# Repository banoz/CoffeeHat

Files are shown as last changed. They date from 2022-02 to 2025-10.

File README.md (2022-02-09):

# CoffeeHat

Basic espresso machine controls on Arduino Nano extension board.

Supports 3-Way valve control, PSM control for a vibe pump based on zero-crossing detector, Qwiic I2C connector for various peripherals (e.g. displays, thermal sensors), full header breakout for Nano pins.

# DISCLAIMER

This project is provided AS-IS, use at your sole discretion and your own risk. Parts of this project can work under dangerous voltages and require special care. Please don't do anything you're not sure about. The maintainer(s) can not be held liable for any suffer or loss or harm or anything else.

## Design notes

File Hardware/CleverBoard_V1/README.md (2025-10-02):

# Clever board

ESP32-C6 based controller board v1 - WIP

```
J10, J11 - AC input
J12 - pump
J13 - 3-way valve

J1 - UART0 (IO16/IO17)
J2 - I2C (IO6/IO7)
J3 - IO8, IO9
J5 - IO3
J6 - Pressure sensor (IO2, 10K/20K voltage divider)
J7 - Brew (IO22) / Steam (IO23) switch
J8 - IO19, IO20, IO21
J9 - 5V SSR control (IO10 -> SSR1, IO11 -> SSR2)

AC zero-cross sense on IO0
Pump control on IO18
3-Way valve control on IO15

I2C port on IO7(I2C1_SCL)/IO6(I2C1_SDA)
```

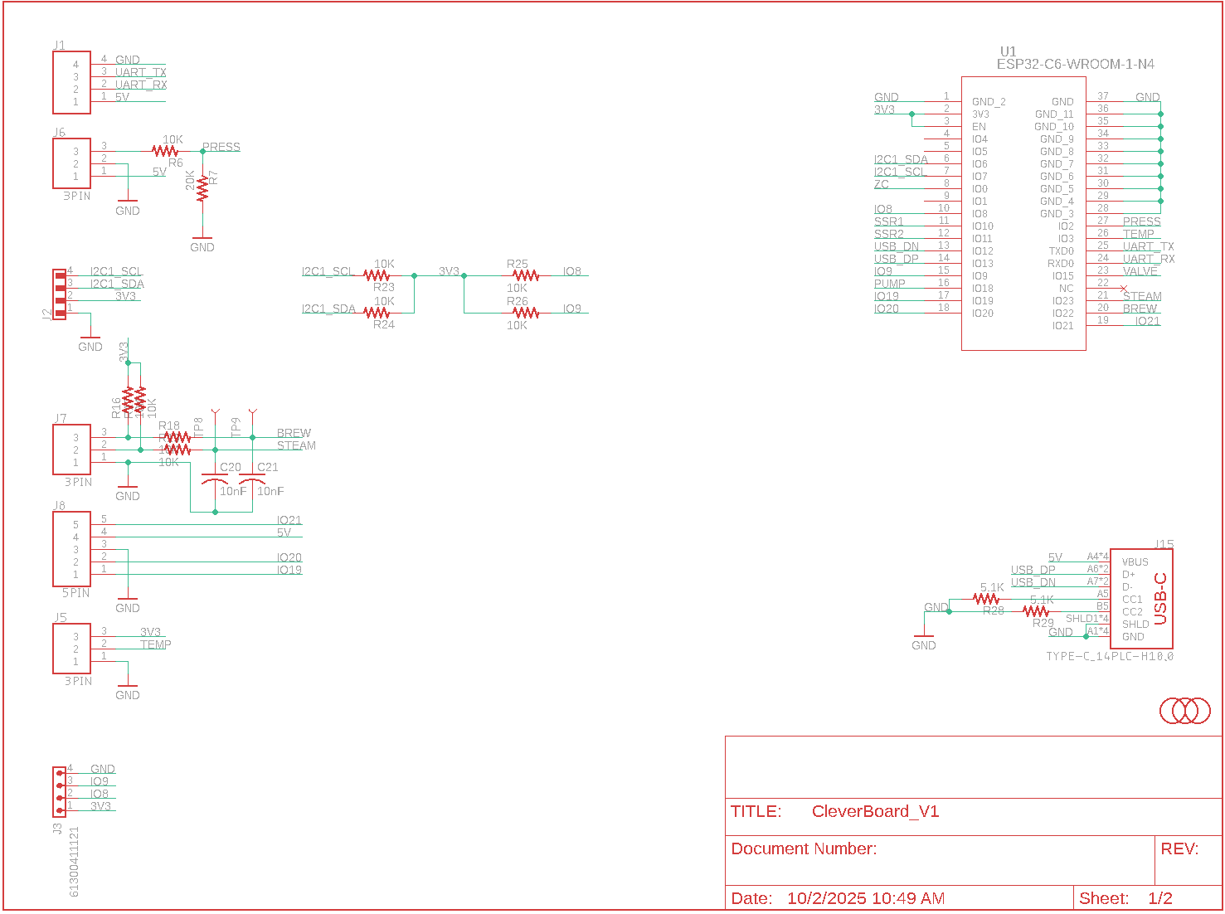
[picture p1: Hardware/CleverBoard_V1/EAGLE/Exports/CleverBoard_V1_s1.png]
CleverBoard_V1_s1

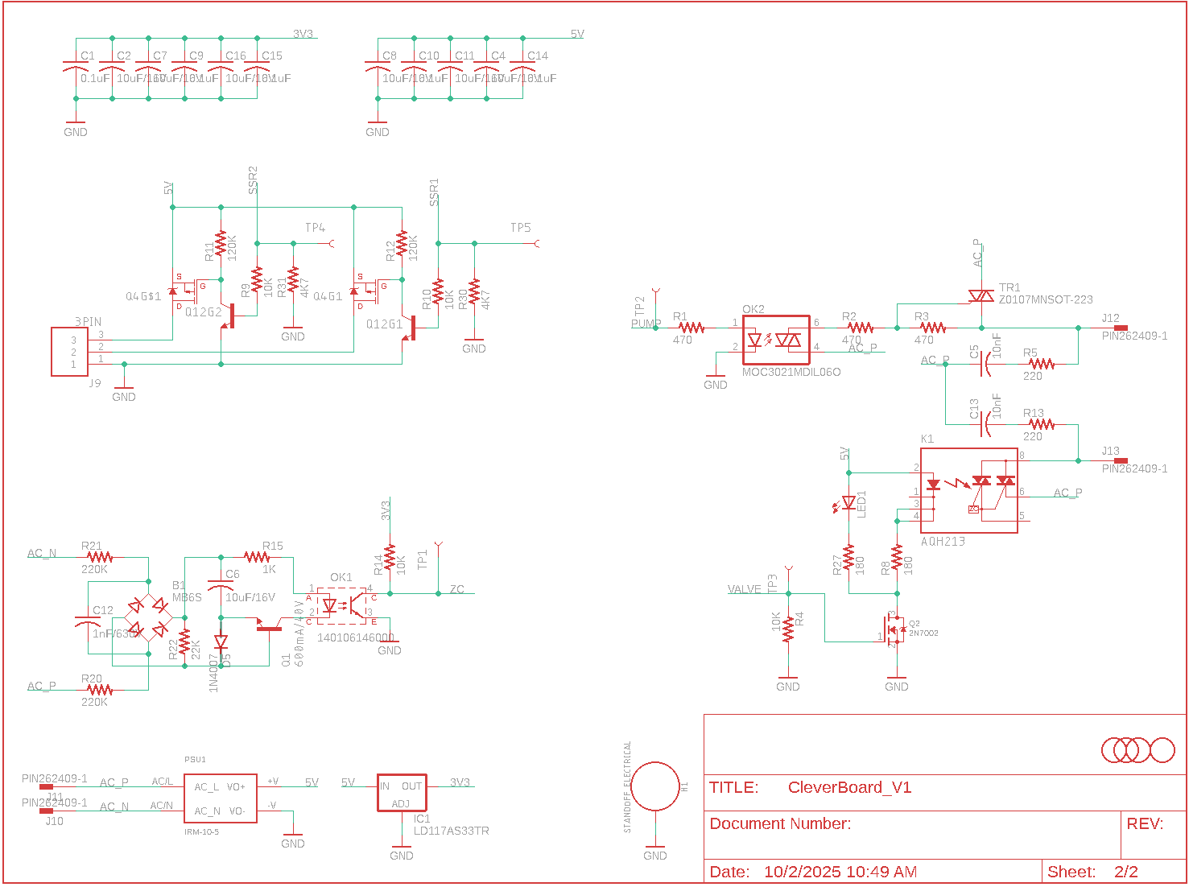
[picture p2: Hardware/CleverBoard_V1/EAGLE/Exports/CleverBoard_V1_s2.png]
CleverBoard_V1_s2


Top|Bottom
---|---
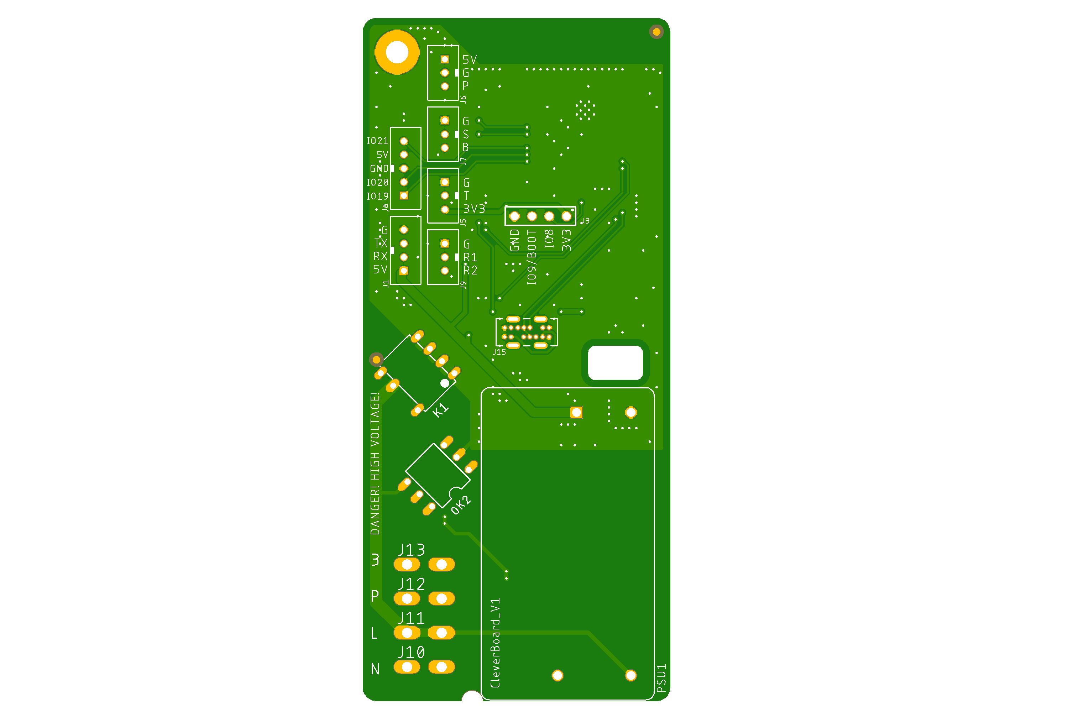
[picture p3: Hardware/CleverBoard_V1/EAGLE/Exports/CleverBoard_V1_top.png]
CleverBoard_V1_top
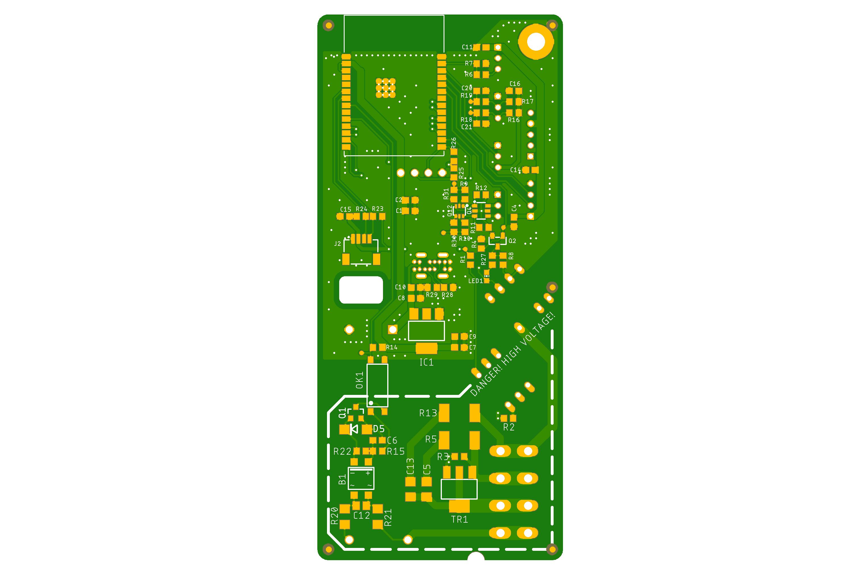
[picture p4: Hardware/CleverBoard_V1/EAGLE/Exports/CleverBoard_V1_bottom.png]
CleverBoard_V1_top
|

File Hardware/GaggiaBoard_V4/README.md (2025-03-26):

# Gaggiuino board

Gaggiuino hardware controller board v4 - WIP

```
J10, J11 - AC input
J12 - pump
J13 - 3-way valve

J1 - UART2 (PA2/PA3)
J2 - I2C
J4 - thermocouple
J5 - PA12, PB15, GND
J6 - Pressure sensor (ADS101X/ADS111X on I2C1)
J7 - Brew (PC14) / Steam (PC15) switch
J8 - Scales (PB0 -> CLK, PB8 -> D1, PB9 -> D2)
J9 - 5V SSR control (PA15 -> SSR1, PA8 -> SSR2)

AC zero-cross sense on PA0
Pump control on PA1
3-Way valve control on PC13

SPI1 is used by thermocouple amplifier on PA5(SPI1_SCK)/PB4(SPI1_MISO), and CS on PA6

I2C port on PB6(I2C1_SCL)/PB7(I2C1_SDA)

J15 - USB-C

J27 - SWD, USART1 (PA9/10), NRST and BOOT1
```

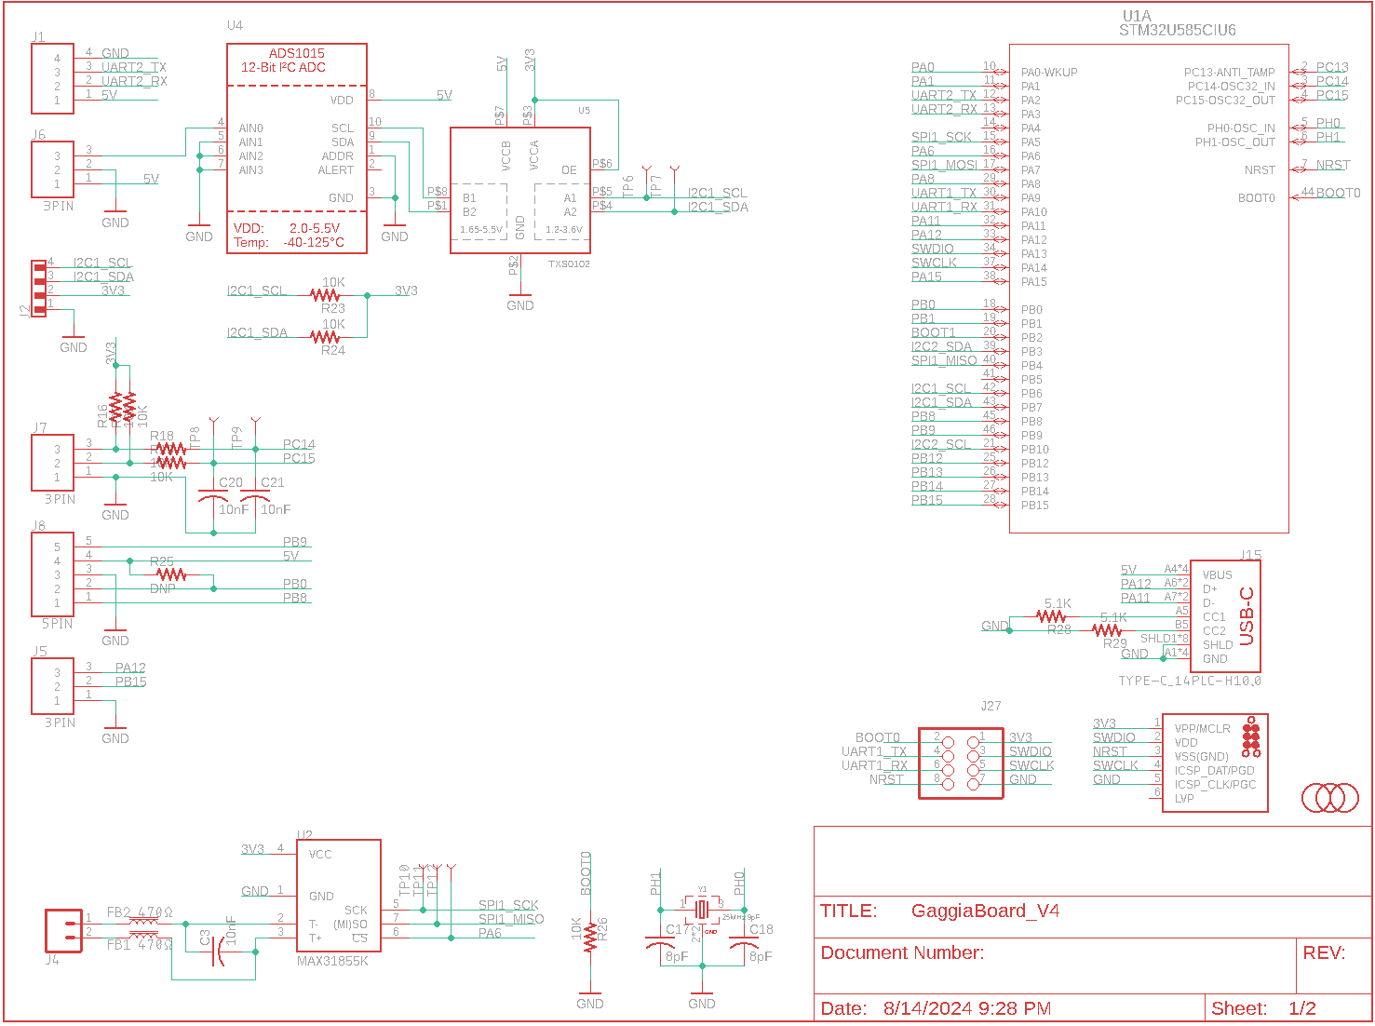
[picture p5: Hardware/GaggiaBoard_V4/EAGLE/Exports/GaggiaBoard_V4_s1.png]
GaggiaBoard_V4_s1

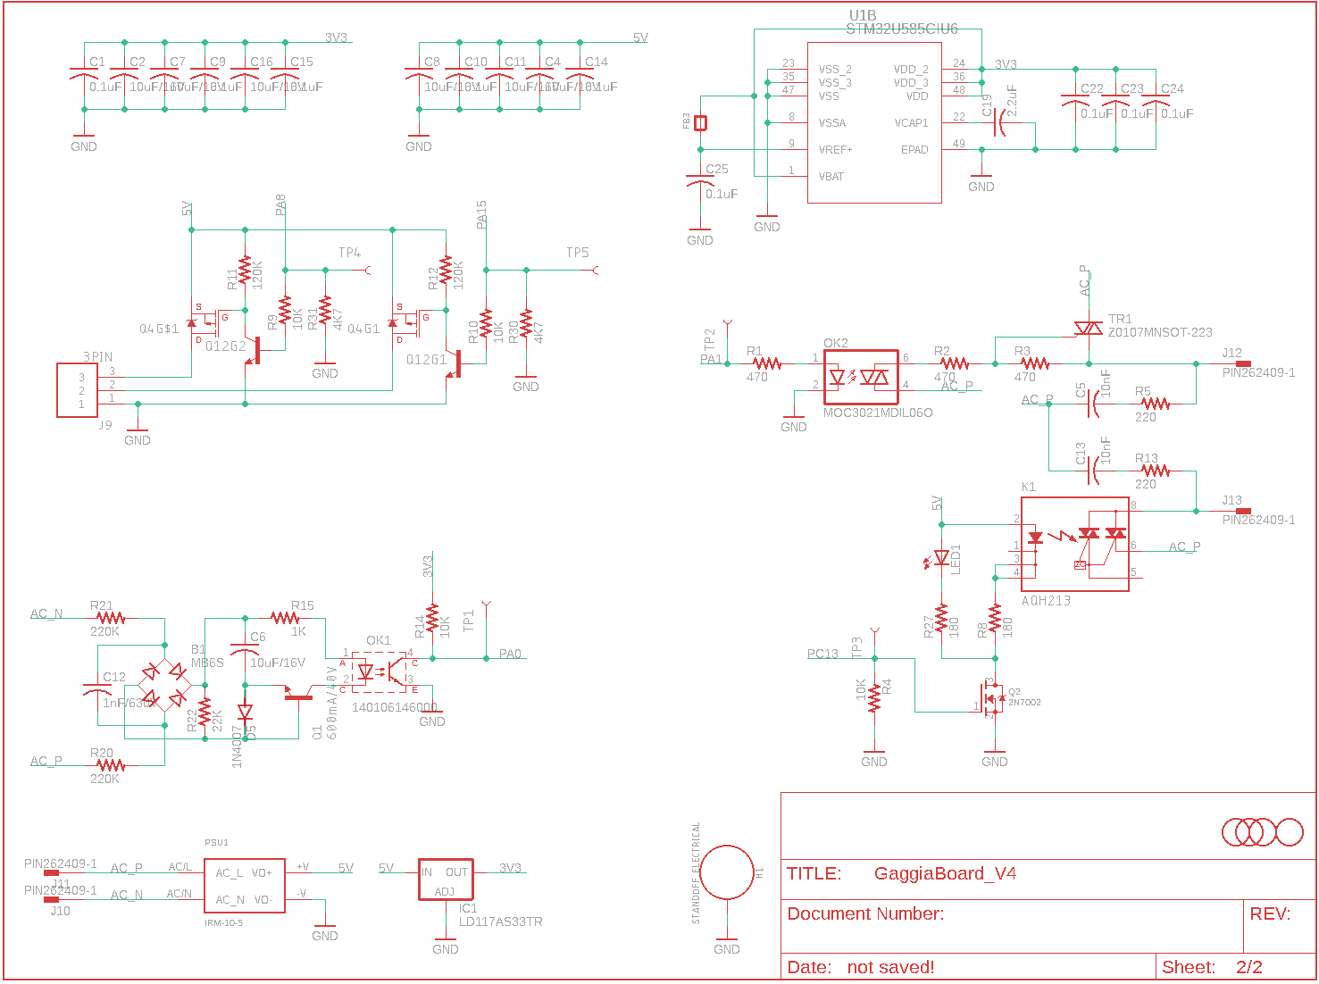
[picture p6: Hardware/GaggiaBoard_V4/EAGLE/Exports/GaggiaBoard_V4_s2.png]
GaggiaBoard_V4_s2


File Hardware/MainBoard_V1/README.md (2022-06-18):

# Generic espresso machine control board

Arduino Nano-based control board for an espresso maker.

**WIP**

SubBoard_V1 is an extension board to use on top of MainBoard_V1 for Gaggiuino.

Pin mapping:  

```
A0 - Pressure transducer

A1 - CLK  \
A2 - D1    -- dual HX711 scales
A3 - D2   /

A4 - I2C SDA
A5 - I2C SCL

D8 - Brew switch
D7 - Steam switch

D0 - NEXTION TX
D1 - NEXTION RX

D3 - AC zero-crossing

D4 - DO   \
D5 - CS    -- MAX31855
D6 - CLK  /

D9 - 3-way valve control
D10 - Pump TRIAC control
D11 - Boiler heater SSR control
```

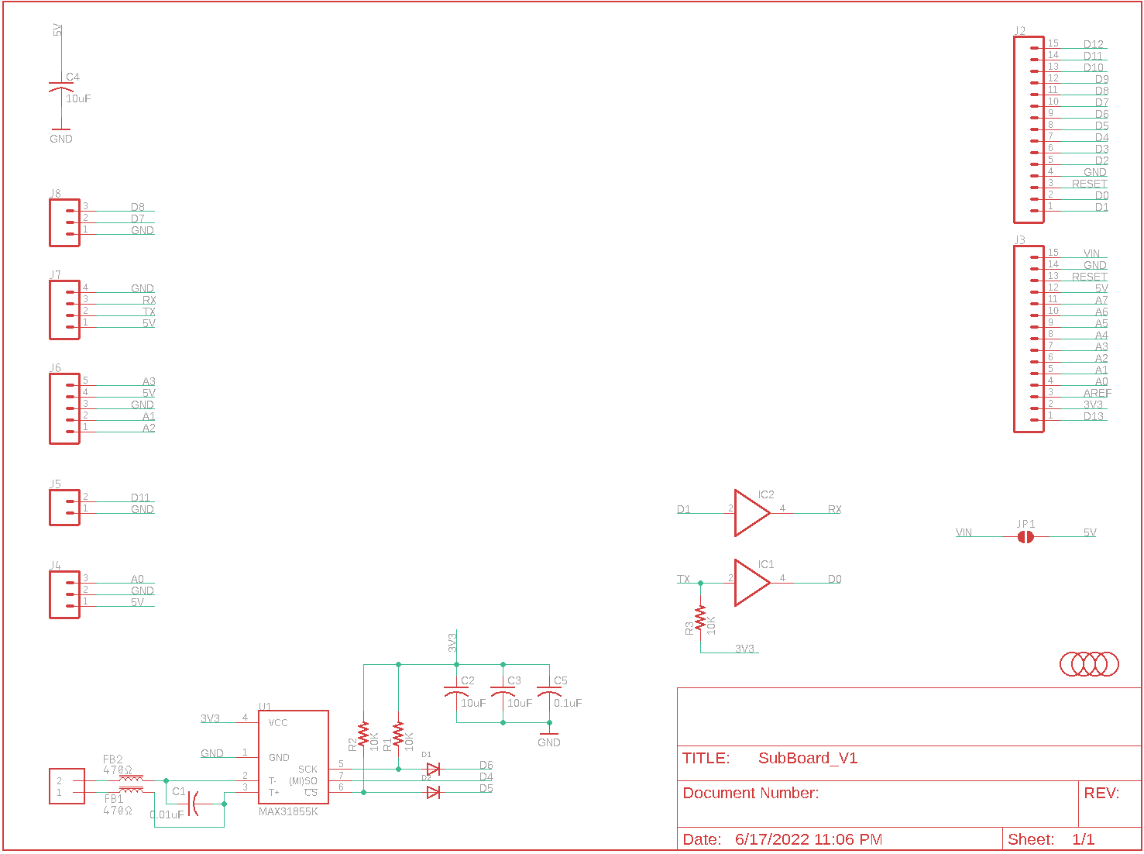
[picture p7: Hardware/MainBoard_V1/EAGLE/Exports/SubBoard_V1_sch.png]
SubBoard_V1_sch

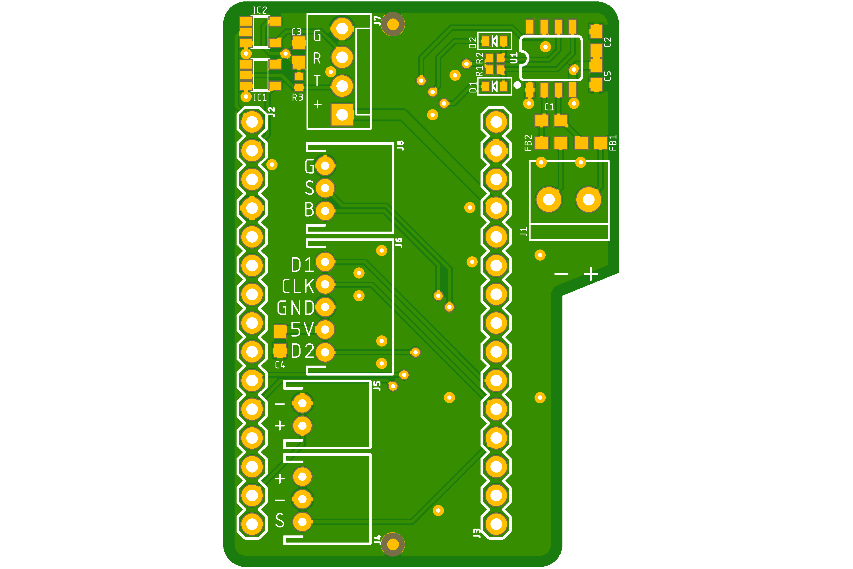
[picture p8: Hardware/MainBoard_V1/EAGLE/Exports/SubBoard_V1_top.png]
SubBoard_V1_top


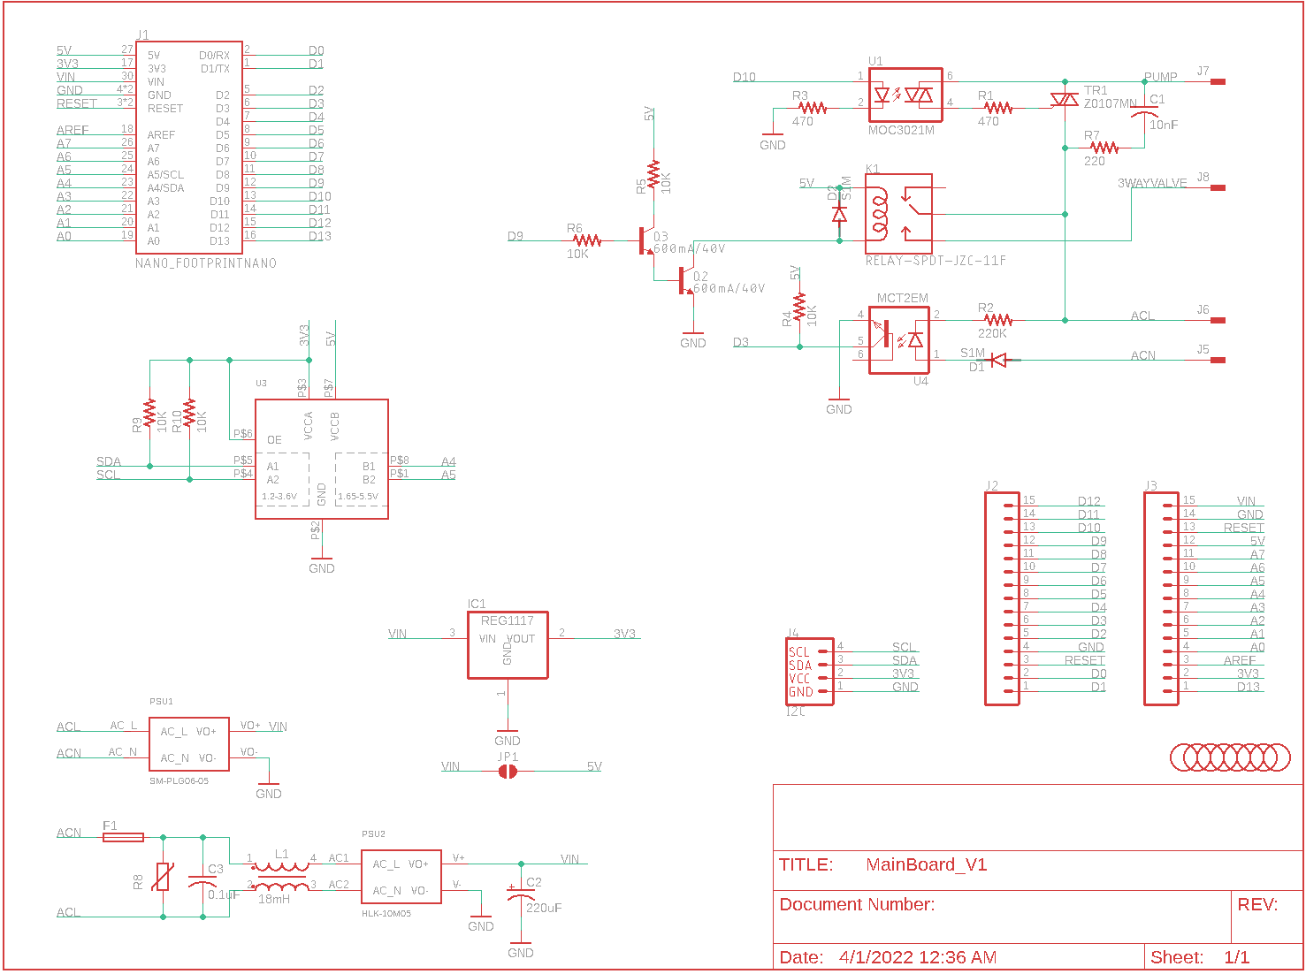
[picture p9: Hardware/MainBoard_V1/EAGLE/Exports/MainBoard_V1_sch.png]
MainBoard_V1_sch

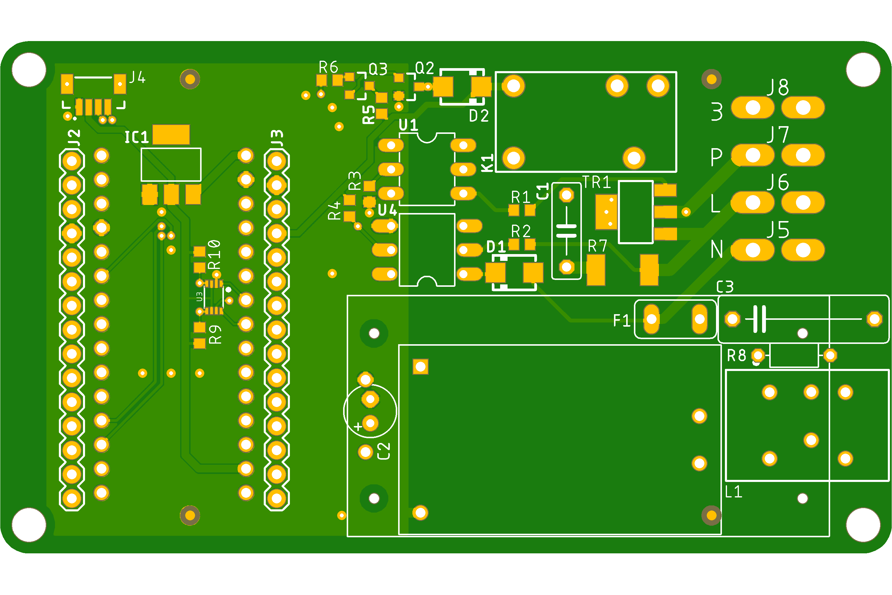
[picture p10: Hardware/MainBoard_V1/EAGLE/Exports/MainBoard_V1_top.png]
MainBoard_V1_top


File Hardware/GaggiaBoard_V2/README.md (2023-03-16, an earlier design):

# Gaggiuino board

Next-gen Gaggiuino hardware controller board - WIP

[3D model](https://github.com/banoz/banoz.github.io/blob/main/repository/stl/GaggiaBoard_V2.stl)

```
J14 - steam boiler heater element
J11 - steam boiler supply valve
J16 - 3-way valve
J17 - pump
J19, J20 - AC input

J1 - UART2 (PA2/PA3)
J2, J3 - I2Cs
J4 - thermocouple
J6 - Pressure sensor (ADS101X/ADS111X on I2C1)
J7 - Brew (PC14) / Steam (PC15) switch
J8 - Scales (PB0 -> CLK, PB8 -> D1, PB9 -> D2)
J9 - 5V SSR control (PA15 -> SSR1, PA8 -> SSR2)

AC zero-cross sense on PA0
Pump control on PA1
Buzzer on PB14
Steam boiler heater element relay on PB13
Steam boiler supply valve relay on PB12
3-Way valve control on PC13

SPI1 is used by thermocouple amplifier on PA5(SPI1_SCK)/PB4(SPI1_MISO), and CS on PA6

Two I2C ports on PB6(I2C1_SCL)/PB7(I2C1_SDA) and PB10(I2C2_SCL)/PB3(I2C2_SDA)

J27 - USART1 (PA9/10) with NRST and BOOT1
```
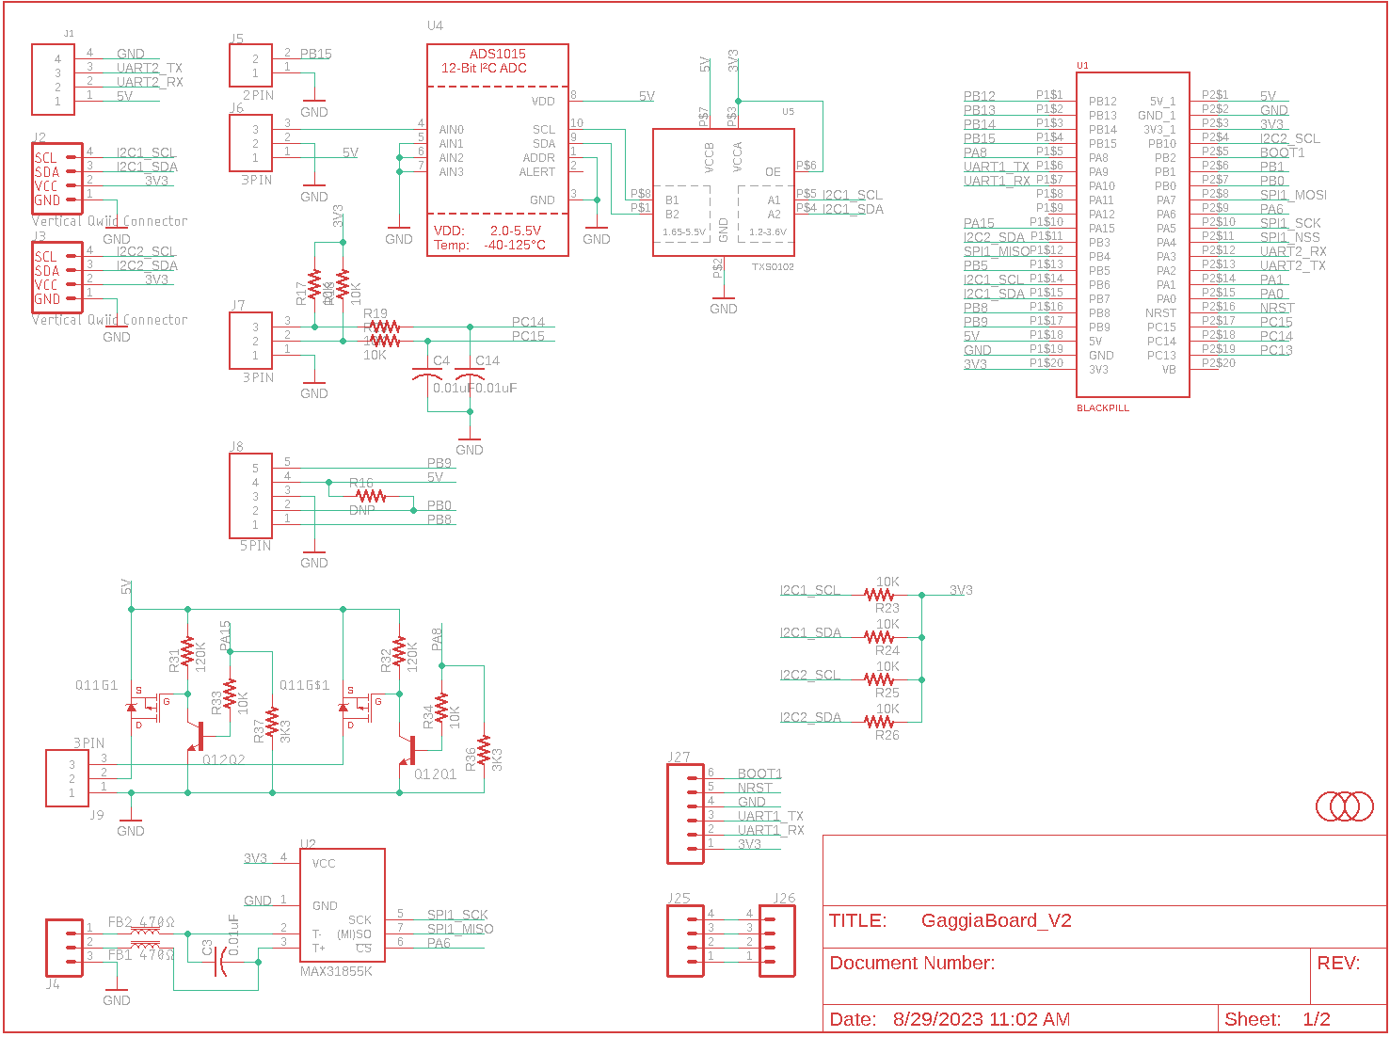
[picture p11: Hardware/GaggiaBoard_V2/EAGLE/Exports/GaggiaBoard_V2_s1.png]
GaggiaBoard_V2_s1

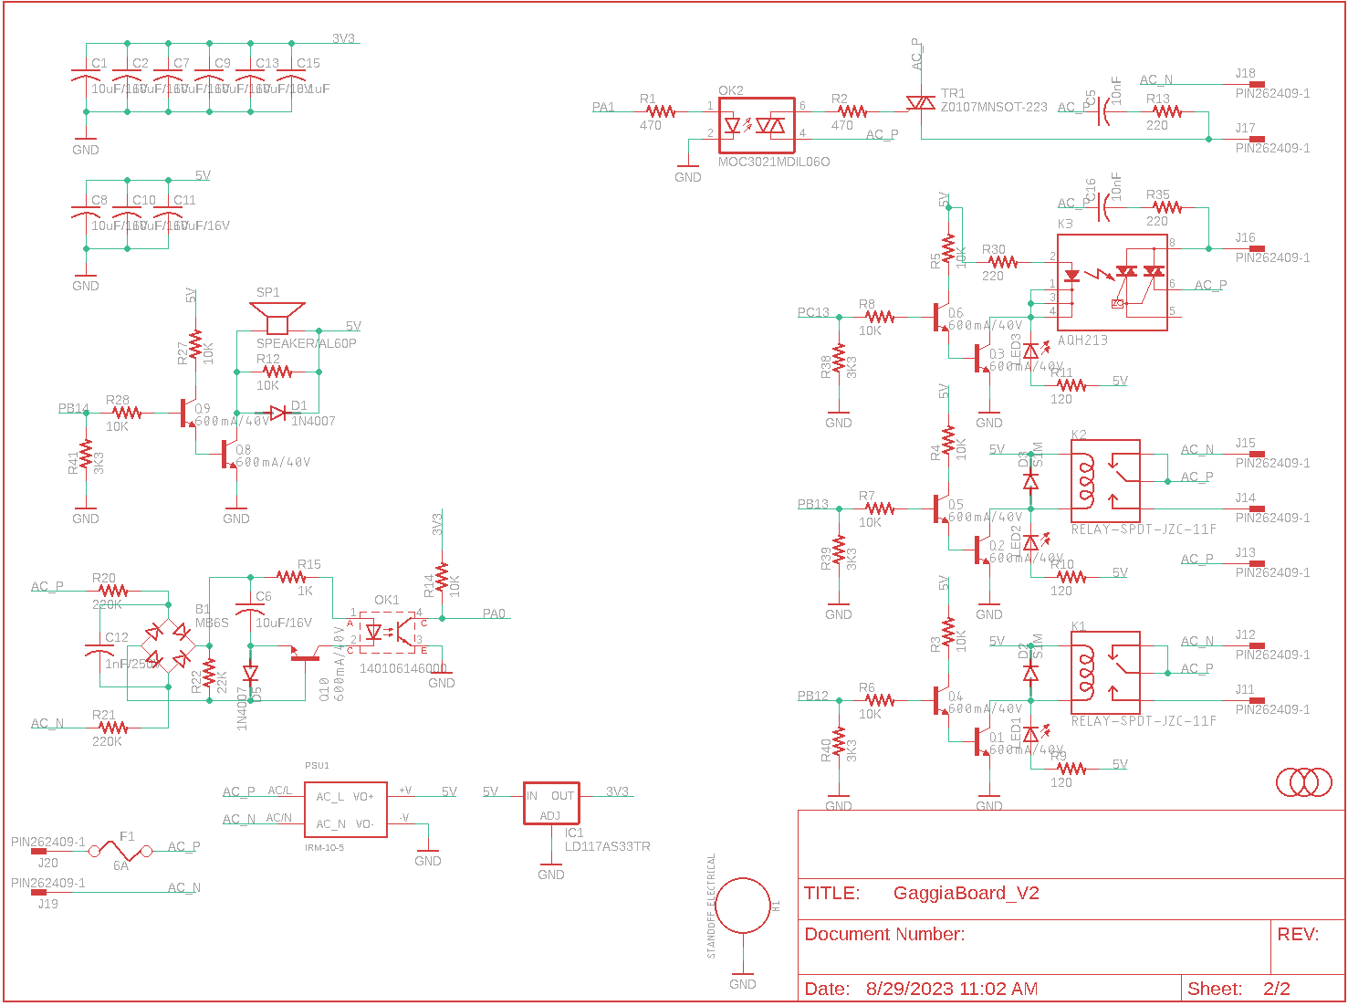
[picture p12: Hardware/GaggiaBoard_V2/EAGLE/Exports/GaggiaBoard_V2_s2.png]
GaggiaBoard_V2_s2

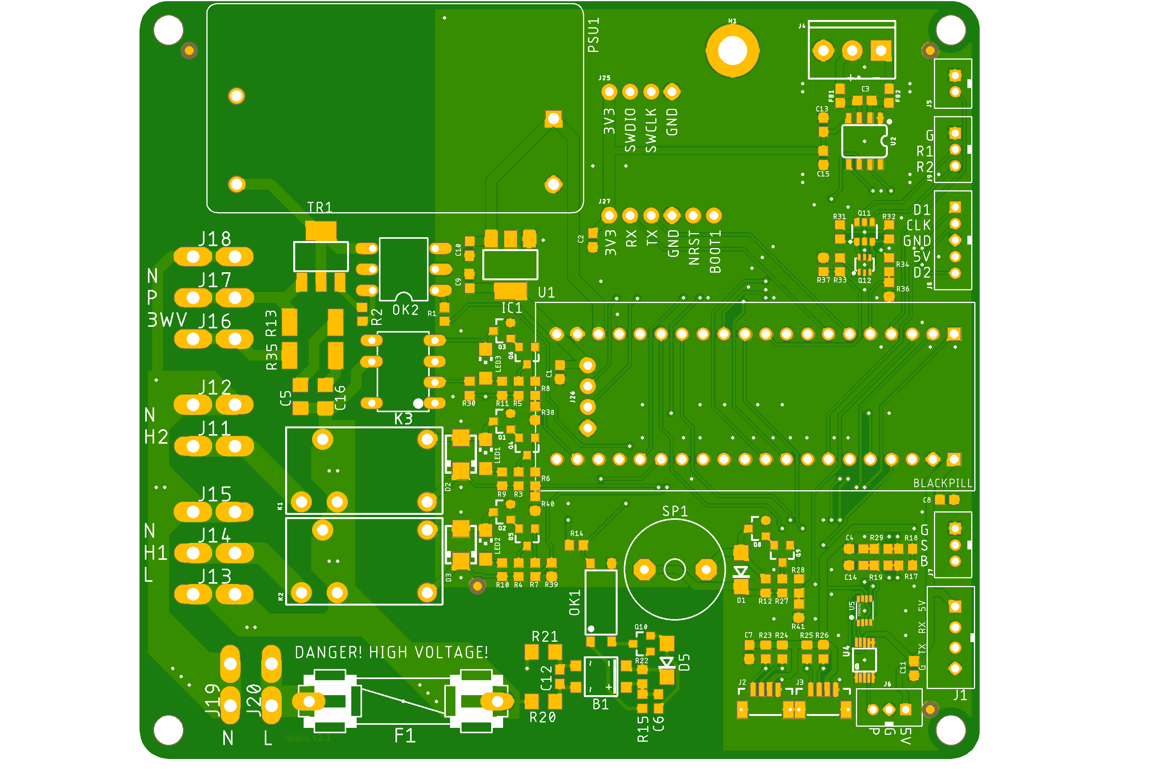
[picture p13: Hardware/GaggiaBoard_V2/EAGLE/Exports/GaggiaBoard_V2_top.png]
GaggiaBoard_V2_top


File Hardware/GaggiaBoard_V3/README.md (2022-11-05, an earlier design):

# Gaggiuino board

Gaggiuino hardware controller board v3 - WIP

[3D model](https://github.com/banoz/banoz.github.io/blob/main/repository/stl/GaggiaBoard_V3.stl)

```
J10, J11 - AC input
J12 - pump
J13 - 3-way valve

J1 - UART2 (PA2/PA3)
J2 - I2C
J4 - thermocouple
J6 - Pressure sensor (ADS101X/ADS111X on I2C1)
J7 - Brew (PC14) / Steam (PC15) switch
J8 - Scales (PB0 -> CLK, PB8 -> D1, PB9 -> D2)
J9 - 5V SSR control (PA15 -> SSR1, PA8 -> SSR2)

AC zero-cross sense on PA0
Pump control on PA1
3-Way valve control on PC13

SPI1 is used by thermocouple amplifier on PA5(SPI1_SCK)/PB4(SPI1_MISO), and CS on PA6

I2C port on PB6(I2C1_SCL)/PB7(I2C1_SDA)

J27 - USART1 (PA9/10) with NRST and BOOT1
```

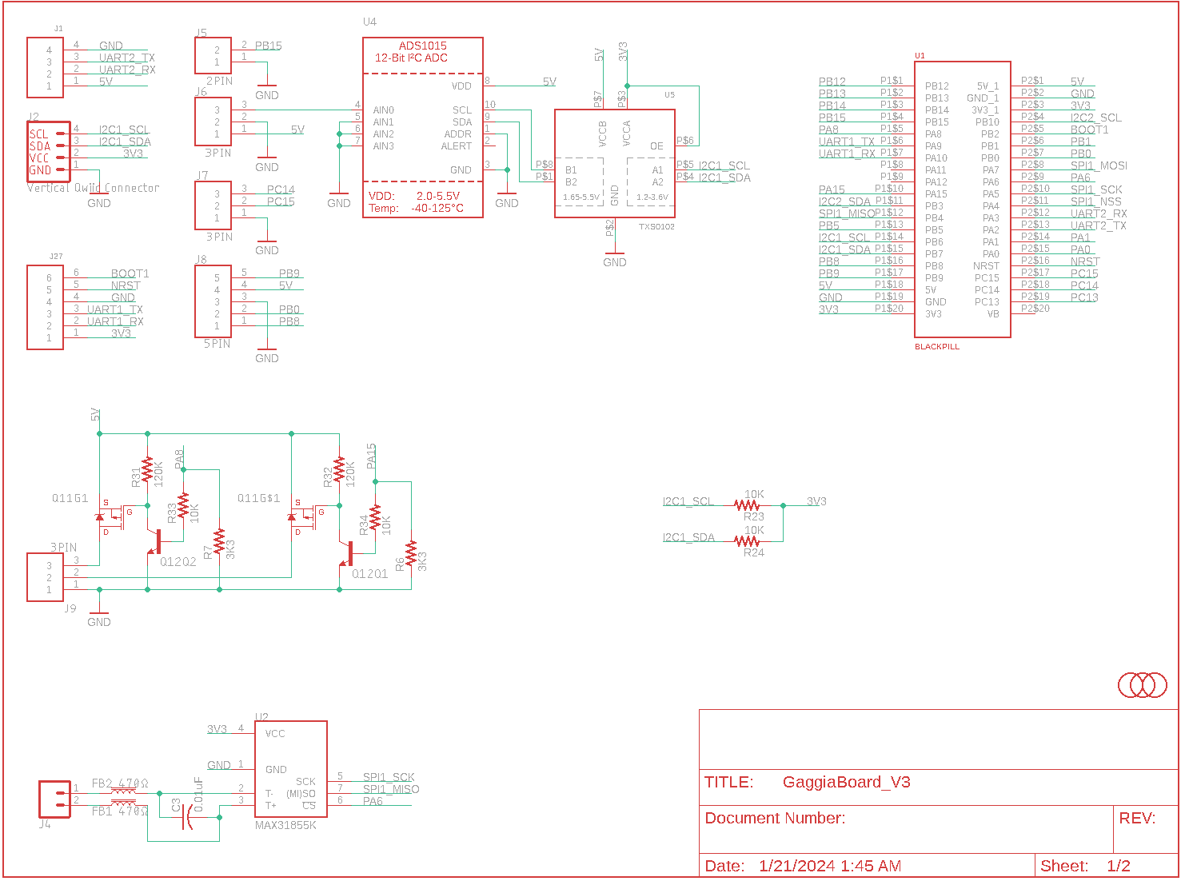
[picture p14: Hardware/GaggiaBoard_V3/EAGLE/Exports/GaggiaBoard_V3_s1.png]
GaggiaBoard_V3_s1

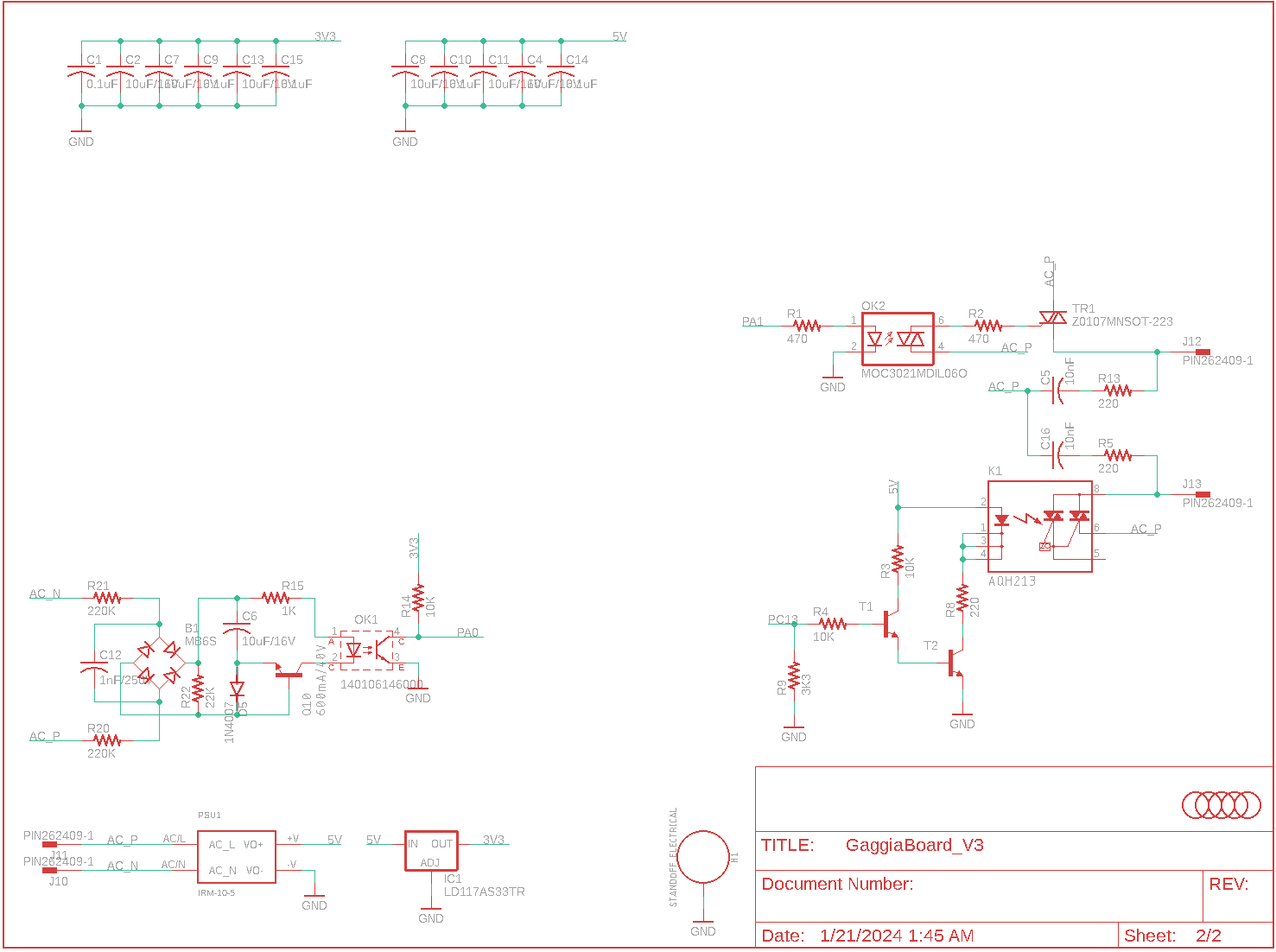
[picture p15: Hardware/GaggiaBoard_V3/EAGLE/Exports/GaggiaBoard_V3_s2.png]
GaggiaBoard_V3_s2


Top|Bottom
---|---
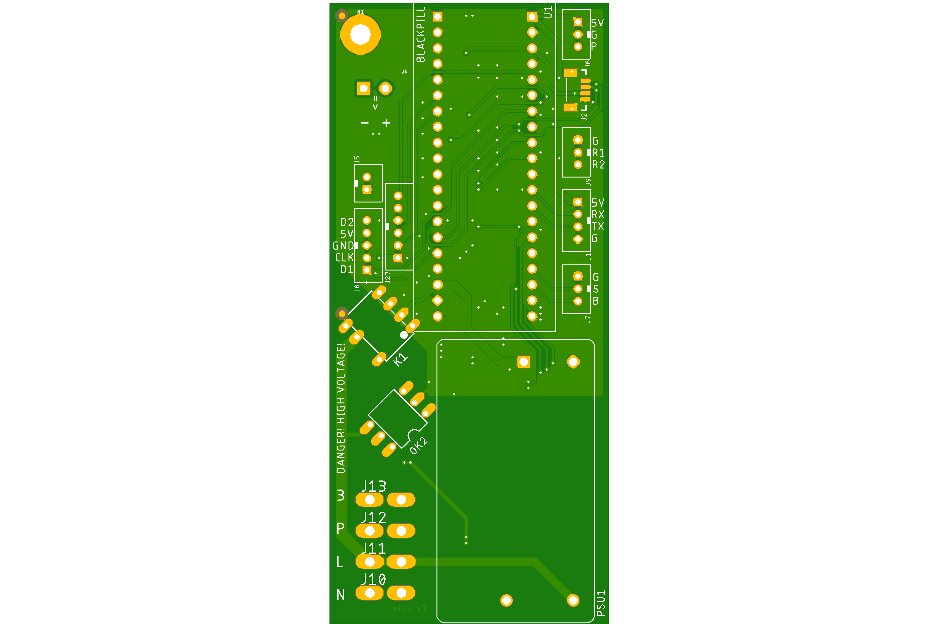
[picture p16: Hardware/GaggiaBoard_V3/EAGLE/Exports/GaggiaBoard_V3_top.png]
GaggiaBoard_V3_top
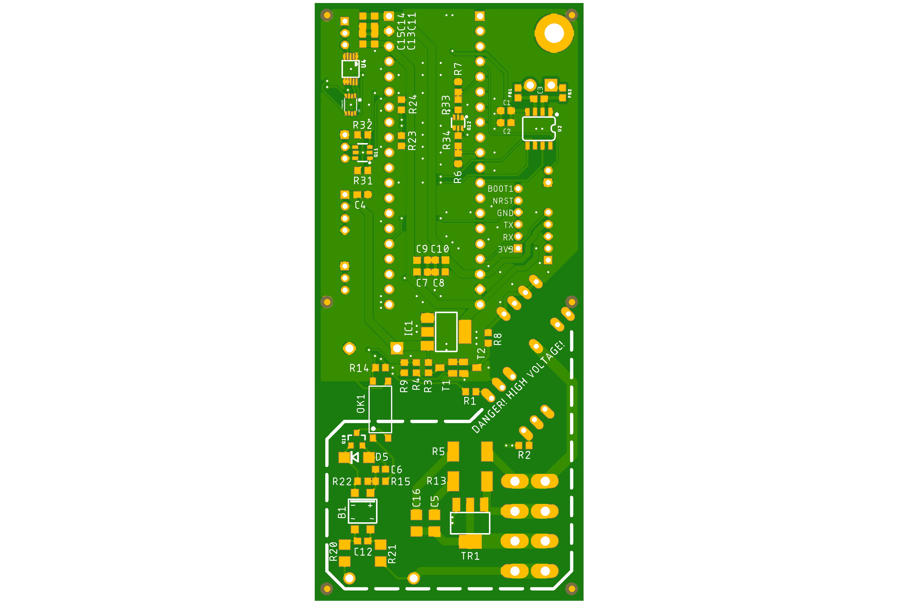
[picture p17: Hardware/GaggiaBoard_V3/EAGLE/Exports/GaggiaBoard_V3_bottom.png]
GaggiaBoard_V3_top
|

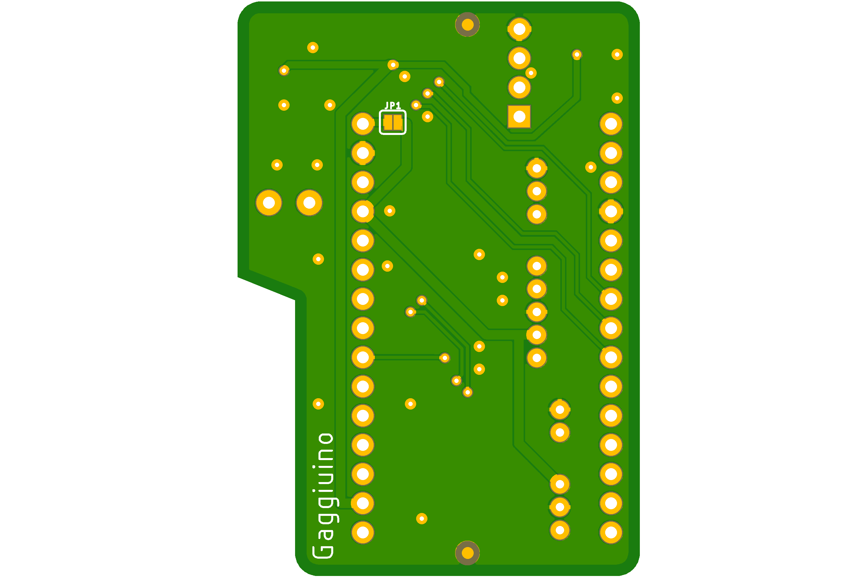
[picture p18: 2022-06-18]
Hardware/MainBoard_V1/EAGLE/Exports/SubBoard_V1_bottom.png

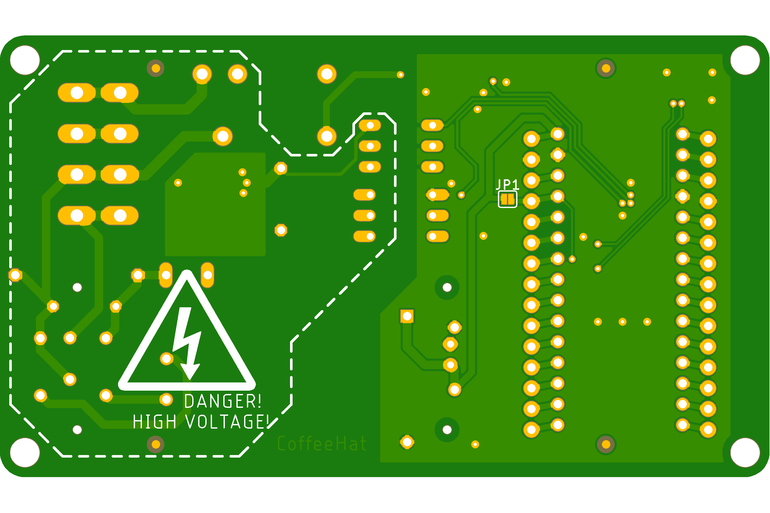
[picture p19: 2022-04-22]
Hardware/MainBoard_V1/EAGLE/Exports/MainBoard_V1_bottom.png

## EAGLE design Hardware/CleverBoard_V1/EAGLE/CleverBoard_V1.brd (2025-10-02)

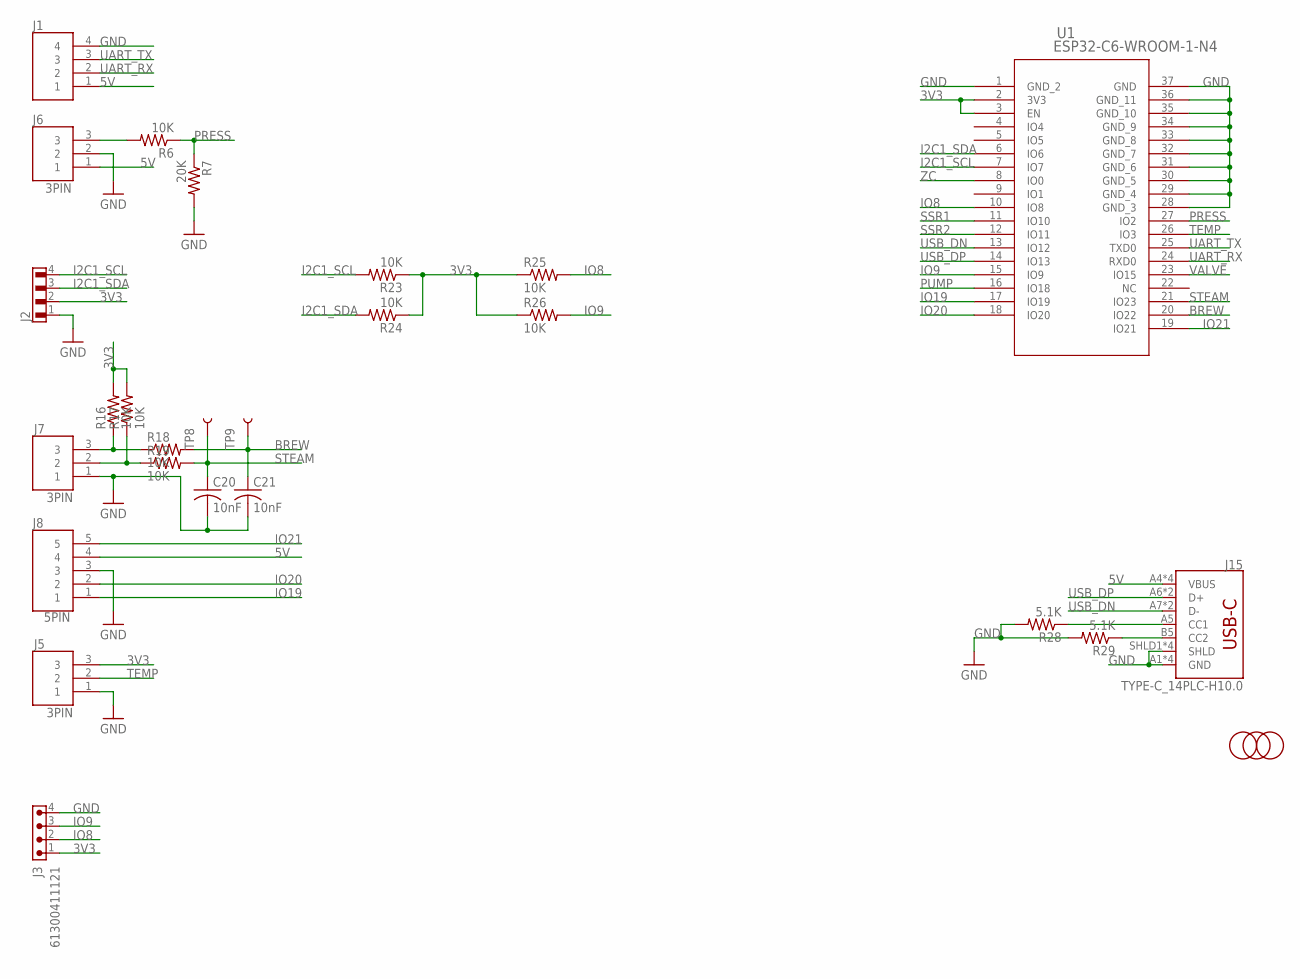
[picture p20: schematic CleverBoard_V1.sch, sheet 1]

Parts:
C20, C21: 10nF; C0603; LCSC C100042
J1: 4PIN; B4B-PH-K-S; LCSC C131334
J2: 665104131822; LCSC C160390
J3: 61300411121; LCSC C2691448
J5, J6, J7: 3PIN; B3B-PH-K-S; LCSC C131339
J8: 5PIN; B5B-PH-K-S; LCSC C157993
J15: TYPE-C_14PLC-H10.0; LCSC C3151746
MARK1, MARK2, MARK5: FIDUCIAL; FIDUCIAL_1MM
R6, R16, R17, R18, R19, R23, R24, R25, R26: 10K; R0603; LCSC C98220
R7: 20K; R0603; LCSC C105575
R28, R29: 5.1K; R0603; LCSC C105580
TP8, TP9: TEST-POINT3; PAD.03X.03
U1: ESP32-C6-WROOM-1-N4; MOD28_ESP32-C6-WROOM-1_EXP; LCSC C5366877

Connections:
3V3: J2.2, J3.1, J5.3, R16.2, R17.2, R23.1, R24.1, R25.1, R26.1, U1.2 (3V3), U1.3 (EN); also elsewhere on the board
5V: J1.1, J6.1, J8.4, J15.A4 (VBUS), J15.A9 (VBUS), J15.B4 (VBUS), J15.B9 (VBUS); also elsewhere on the board
BREW: C21.1, R18.2, TP9.1, U1.20 (IO22)
CC1: J15.A5 (CC1), R28.1
CC2: J15.B5 (CC2), R29.1
GND: C20.2, C21.2, J1.4, J2.1, J3.4, J5.1, J6.2, J7.1, J8.3, J15.A1 (GND), J15.A12 (GND), J15.B1 (GND), J15.B12 (GND), J15.SHLD1 (SHLD), J15.SHLD2 (SHLD), J15.SHLD3 (SHLD), J15.SHLD4 (SHLD), R7.2, R28.2, R29.2, U1.1 (GND_2), U1.28 (GND_3), U1.29 (GND_4), U1.30 (GND_5), U1.31 (GND_6), U1.32 (GND_7), U1.33 (GND_8), U1.34 (GND_9), U1.35 (GND_10), U1.36 (GND_11), U1.37 (GND); also elsewhere on the board
I2C1_SCL: J2.4, R23.2, U1.7 (IO7)
I2C1_SDA: J2.3, R24.2, U1.6 (IO6)
IO8: J3.2, R25.2, U1.10 (IO8)
IO9: J3.3, R26.2, U1.15 (IO9)
IO19: J8.1, U1.17 (IO19)
IO20: J8.2, U1.18 (IO20)
IO21: J8.5, U1.19 (IO21)
unnamed: J7.3, R16.1, R18.1
unnamed: J7.2, R17.1, R19.1
unnamed: J6.3, R6.2
PRESS: R6.1, R7.1, U1.27 (IO2)
PUMP: U1.16 (IO18); also elsewhere on the board
SSR1: U1.11 (IO10); also elsewhere on the board
SSR2: U1.12 (IO11); also elsewhere on the board
STEAM: C20.1, R19.2, TP8.1, U1.21 (IO23)
TEMP: J5.2, U1.26 (IO3)
UART_RX: J1.2, U1.24 (RXD0)
UART_TX: J1.3, U1.25 (TXD0)
USB_DN: J15.A7 (D-), J15.B7 (D-), U1.13 (IO12)
USB_DP: J15.A6 (D+), J15.B6 (D+), U1.14 (IO13)
VALVE: U1.23 (IO15); also elsewhere on the board
ZC: U1.8 (IO0); also elsewhere on the board

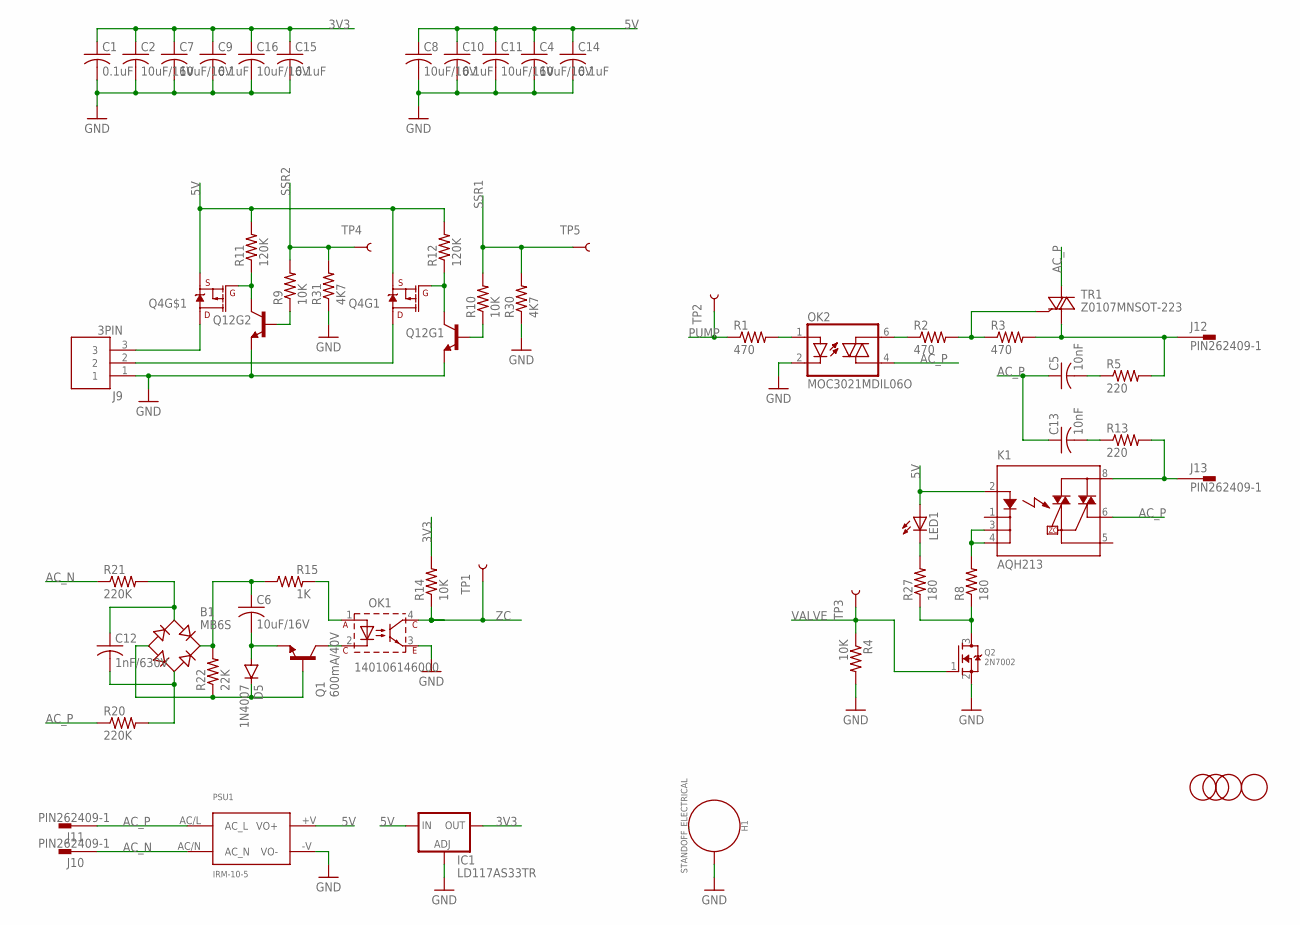
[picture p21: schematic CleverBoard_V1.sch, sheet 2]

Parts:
B1: MB6S; SOIC-4; LCSC C2487
C1, C9, C10, C14, C15: 0.1uF; C0603; LCSC C1591
C2, C4, C6, C7, C8, C11, C16: 10uF/16V; C0603; LCSC C86275
C5, C13: 10nF; C1206; LCSC C107192
C12: 1nF/630V; C0805; LCSC C501242
D5: 1N4007; DO214AC; LCSC C727081
H1: STANDOFF_ELECTRICAL; STANDOFF-ELECTRICAL
IC1: LD117AS33TR; SOT223; LCSC C26537
J9: 3PIN; B3B-PH-K-S; LCSC C131339
J10, J11, J12, J13: PIN262409-1; 62409-1; LCSC C86495
K1: AQH213; DIL07; LCSC C719560
LED1: LEDCHIP-LED0603; CHIP-LED0603; LCSC C2286
MARK4, MARK6, MARK7, MARK8: FIDUCIAL; FIDUCIAL_1MM
OK1: 140106146000; WL-OCPT_LSOP4; LCSC C141610
OK2: MOC3021MDIL06O; DIL06O; LCSC C5242
PSU1: IRM-10-5; IRM-10; LCSC C2857903
Q1: 600mA/40V; SOT23-3; LCSC C82460
Q2: 2N7002; SOT23-R; LCSC C65189
Q4: MOSFET_PCH_DUAL-DMP2240UDM; SOT26; LCSC C397948
Q12: TRANS_NPN_DUAL-MBT3904DW1T1; SC70-6; LCSC C896759
R1, R2, R3: 470; R0603; LCSC C114669
R4, R9, R10, R14: 10K; R0603; LCSC C98220
R5, R13: 220; R2512; LCSC C877859
R8, R27: 180; R0603; LCSC C137786
R11, R12: 120K; R0603; LCSC C114607
R15: 1K; R0603; LCSC C22548
R20, R21: 220K; R1206; LCSC C130275
R22: 22K; R0603; LCSC C114065
R30, R31: 4K7; R0603; LCSC C99782
TP1, TP2, TP3, TP4, TP5: TEST-POINT3; PAD.03X.03
TR1: Z0107MNSOT-223; SOT223; LCSC C71218

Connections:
3V3: C1.1, C2.1, C7.1, C9.1, C15.1, C16.1, IC1.4 (OUT), R14.2; also elsewhere on the board
3WAY: J13.A1, J13.A2, K1.8 (DS1), R13.2
5V: C4.1, C8.1, C10.1, C11.1, C14.1, IC1.3 (IN), K1.2 (A), LED1.A, PSU1.+V (VO+), Q4.S1 (S), Q4.S2 (S), R11.2, R12.2; also elsewhere on the board
AC_N: J10.A1, J10.A2, PSU1.AC/N (AC_N), R21.1
AC_P: C5.1, C13.1, J11.A1, J11.A2, K1.6 (DS3), OK2.4 (A1), PSU1.AC/L (AC_L), R20.1, TR1.2 (A2), TR1.4 (A2)
GND: C1.2, C2.2, C4.2, C7.2, C8.2, C9.2, C10.2, C11.2, C14.2, C15.2, C16.2, H1.P1, IC1.1 (ADJ), J9.1, OK1.3, OK2.2 (C), PSU1.-V (VO-), Q2.2 (S), Q12.1 (E), Q12.4 (E), R4.2, R30.1, R31.1; also elsewhere on the board
unnamed: B1.-, D5.C, Q1.1 (B), R22.1
unnamed: LED1.C, R27.2
unnamed: OK2.6 (A2), R2.1
unnamed: OK1.2, Q1.3 (C)
unnamed: R2.2, R3.1, TR1.3 (G)
unnamed: Q2.3 (D), R8.1, R27.1
unnamed: K1.3 (K1), K1.4 (K2), R8.2
unnamed: C13.2, R13.1
unnamed: C5.2, R5.1
unnamed: B1.~1 (AC1), C12.2, R20.2
unnamed: B1.~2 (AC2), C12.1, R21.2
unnamed: OK2.1 (A), R1.2
unnamed: C6.2, D5.A, Q1.2 (E)
unnamed: OK1.1, R15.2
unnamed: B1.+, C6.1, R15.1, R22.2
unnamed: Q12.2 (B), R9.1
unnamed: Q4.G1 (G), Q12.3 (C), R12.1
unnamed: Q4.G2 (G), Q12.6 (C), R11.1
unnamed: Q12.5 (B), R10.1
PUMP: R1.1, TP2.1; also elsewhere on the board
PUMP_P: J12.A1, J12.A2, R3.2, R5.2, TR1.1 (A1)
R1: J9.2, Q4.D1 (D)
R2: J9.3, Q4.D2 (D)
SSR1: R10.2, R30.2, TP5.1; also elsewhere on the board
SSR2: R9.2, R31.2, TP4.1; also elsewhere on the board
VALVE: Q2.1 (G), R4.1, TP3.1; also elsewhere on the board
ZC: OK1.4, R14.1, TP1.1; also elsewhere on the board

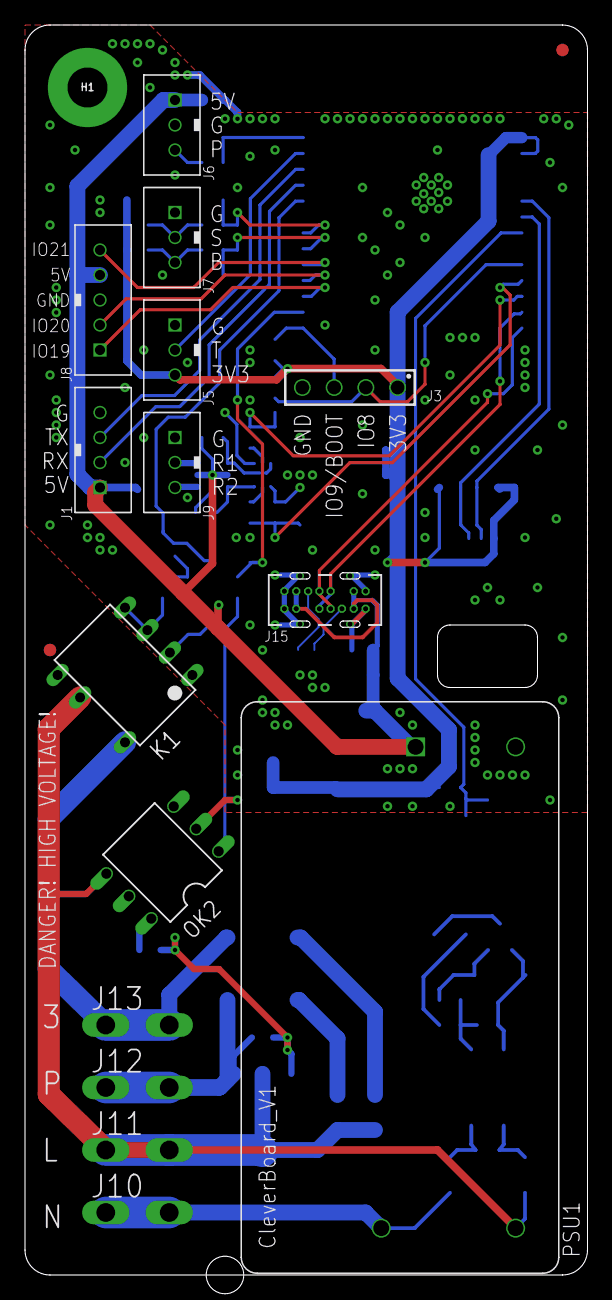
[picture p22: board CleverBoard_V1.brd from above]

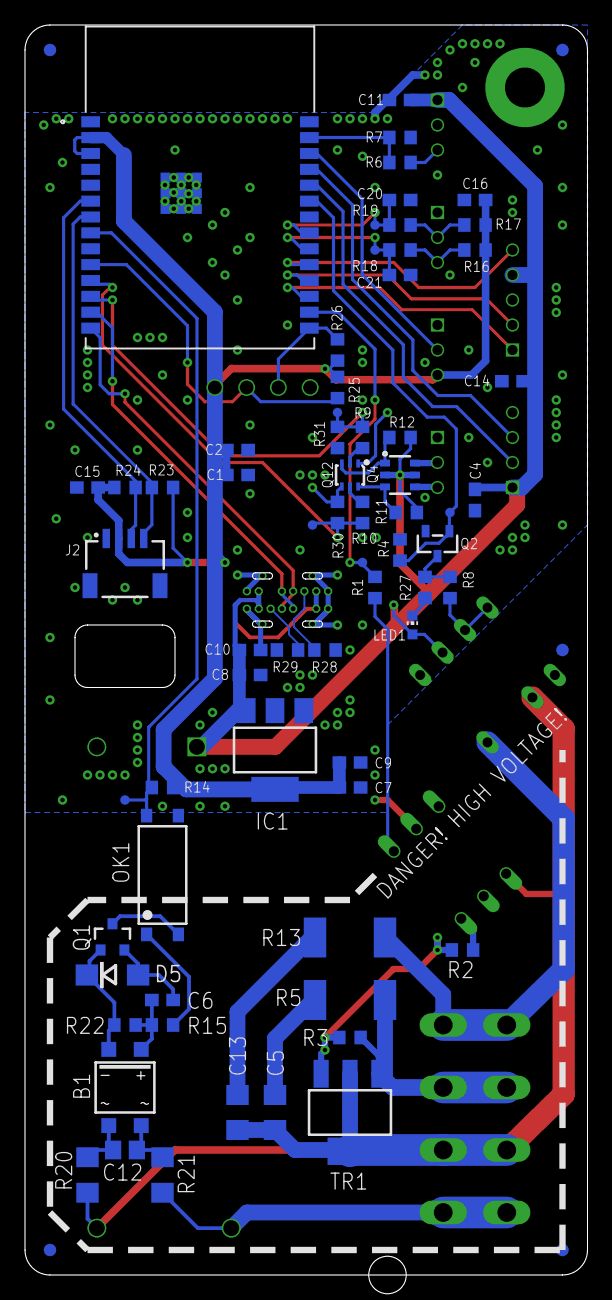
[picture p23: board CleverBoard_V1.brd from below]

Board: 2 copper layers, 45.0 x 100.0 mm, 90 parts (72 on the bottom side), 53 nets.

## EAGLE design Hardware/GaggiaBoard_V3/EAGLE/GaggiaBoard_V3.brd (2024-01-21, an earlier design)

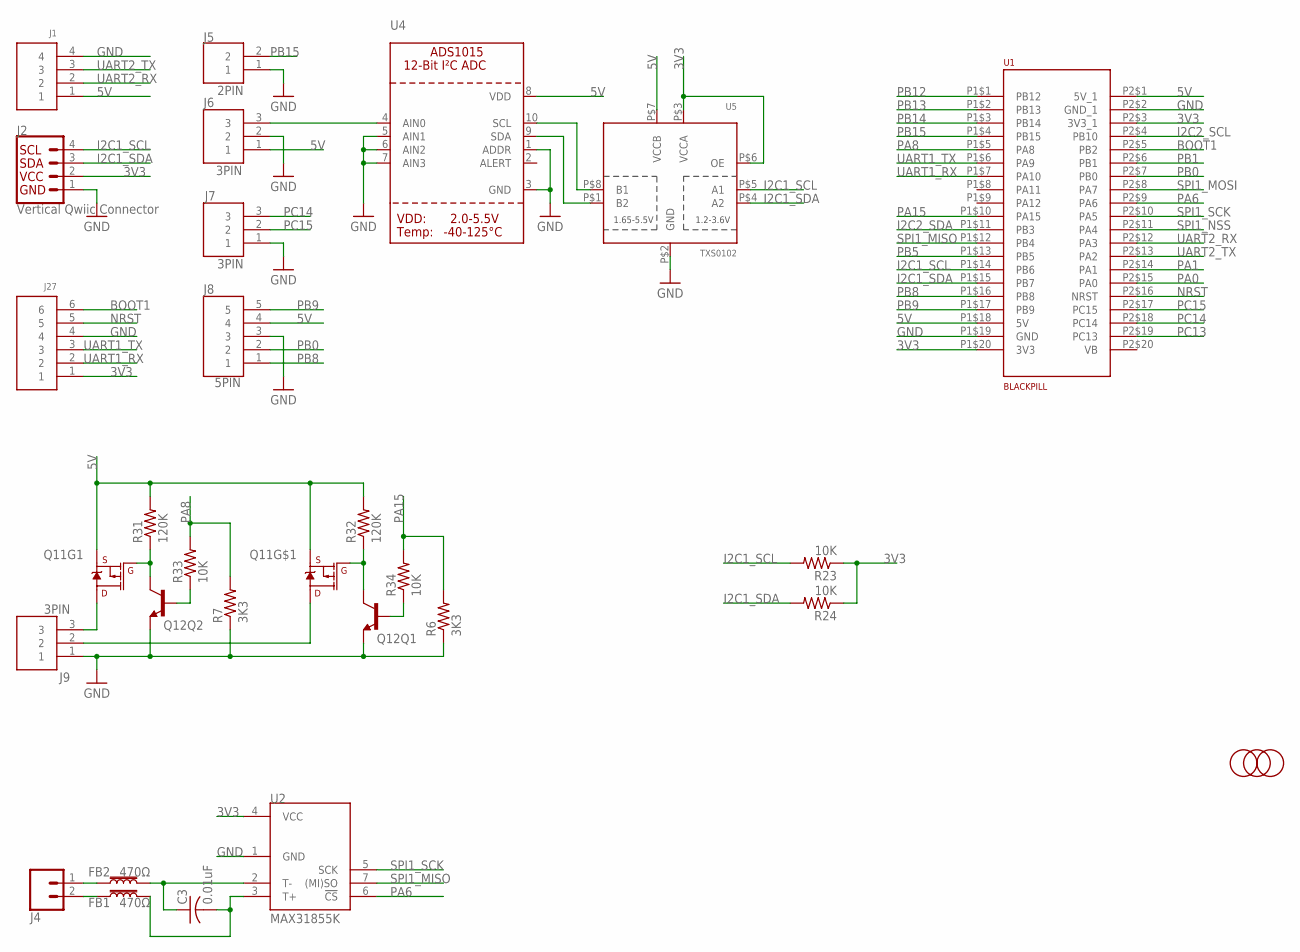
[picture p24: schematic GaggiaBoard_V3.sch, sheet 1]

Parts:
C3: 0.01uF; C0603; LCSC C100042
FB1, FB2: 470Ω; 0603; LCSC C883591
J1: 4PIN; B4B-PH-K-S; LCSC C131334
J2: Vertical Qwiic Connector; JST04_1MM_VERT; LCSC C160390
J4: CONN_023.5MM-NO_SILK; SCREWTERMINAL-3.5MM-2-NS; LCSC C474892
J5: 2PIN; B2B-PH-K-S; LCSC C131337
J6, J7, J9: 3PIN; B3B-PH-K-S; LCSC C131339
J8: 5PIN; B5B-PH-K-S; LCSC C157993
J27: 6PIN; B6B-PH-K-S; LCSC C131342
MARK1, MARK2, MARK5: FIDUCIAL; FIDUCIAL_1MM
Q11: MOSFET_PCH_DUAL-DMP2240UDM; SOT26; LCSC C397948
Q12: TRANS_NPN_DUAL-MBT3904DW1T1; SC70-6; LCSC C896759
R6, R7: 3K3; R0603; LCSC C114432
R23, R24, R33, R34: 10K; R0603; LCSC C98220
R31, R32: 120K; R0603; LCSC C114607
U1: BLACKPILL
U2: MAX31855K; SO08; LCSC C52028
U4: ADC_ADS1015; MSOP10; LCSC C193969
U5: TXS0102; VFSOP-8; LCSC C53434

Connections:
3V3: J2.2, J27.1, R23.1, R24.1, U1.P1$20 (3V3), U1.P2$3 (3V3_1), U2.4 (VCC), U5.P$3 (VCCA), U5.P$6 (OE); also elsewhere on the board
5V: J1.1, J6.1, J8.4, Q11.S1 (S), Q11.S2 (S), R31.2, R32.2, U1.P1$18 (5V), U1.P2$1 (5V_1), U4.8 (VDD), U5.P$7 (VCCB); also elsewhere on the board
BOOT1: J27.6, U1.P2$5 (PB2)
GND: J1.4, J2.1, J5.1, J6.2, J7.1, J8.3, J9.1, J27.4, Q12.1 (E), Q12.4 (E), R6.1, R7.1, U1.P1$19 (GND), U1.P2$2 (GND_1), U2.1 (GND), U4.1 (ADDR), U4.3 (GND), U4.5 (AIN1), U4.6 (AIN2), U4.7 (AIN3), U5.P$2 (GND); also elsewhere on the board
I2C1_SCL: J2.4, R23.2, U1.P1$14 (PB6), U5.P$5 (A1)
I2C1_SDA: J2.3, R24.2, U1.P1$15 (PB7), U5.P$4 (A2)
I2C2_SCL: U1.P2$4 (PB10)
I2C2_SDA: U1.P1$11 (PB3)
unnamed: FB2.1, J4.1
unnamed: FB1.1, J4.2
unnamed: C3.1, FB2.2, U2.2 (T-)
unnamed: J9.3, Q11.D1 (D)
unnamed: J9.2, Q11.D2 (D)
unnamed: U4.10 (SCL), U5.P$8 (B1)
unnamed: C3.2, FB1.2, U2.3 (T+)
unnamed: U4.9 (SDA), U5.P$1 (B2)
unnamed: Q12.2 (B), R33.1
unnamed: Q11.G2 (G), Q12.3 (C), R32.1
unnamed: Q11.G1 (G), Q12.6 (C), R31.1
unnamed: Q12.5 (B), R34.1
NRST: J27.5, U1.P2$16 (NRST)
PA0: U1.P2$15 (PA0); also elsewhere on the board
PA1: U1.P2$14 (PA1); also elsewhere on the board
PA6: U1.P2$9 (PA6), U2.6 (!CS)
PA8: R7.2, R33.2, U1.P1$5 (PA8)
PA15: R6.2, R34.2, U1.P1$10 (PA15)
PB0: J8.2, U1.P2$7 (PB0)
PB1: U1.P2$6 (PB1)
PB5: U1.P1$13 (PB5)
PB8: J8.1, U1.P1$16 (PB8)
PB9: J8.5, U1.P1$17 (PB9)
PB12: U1.P1$1 (PB12)
PB13: U1.P1$2 (PB13)
PB14: U1.P1$3 (PB14)
PB15: J5.2, U1.P1$4 (PB15)
PC13: U1.P2$19 (PC13); also elsewhere on the board
PC14: J7.3, U1.P2$18 (PC14)
PC15: J7.2, U1.P2$17 (PC15)
PRESSURE: J6.3, U4.4 (AIN0)
SPI1_MISO: U1.P1$12 (PB4), U2.7 ((MI)SO)
SPI1_MOSI: U1.P2$8 (PA7)
SPI1_NSS: U1.P2$11 (PA4)
SPI1_SCK: U1.P2$10 (PA5), U2.5 (SCK)
UART1_RX: J27.2, U1.P1$7 (PA10)
UART1_TX: J27.3, U1.P1$6 (PA9)
UART2_RX: J1.2, U1.P2$12 (PA3)
UART2_TX: J1.3, U1.P2$13 (PA2)

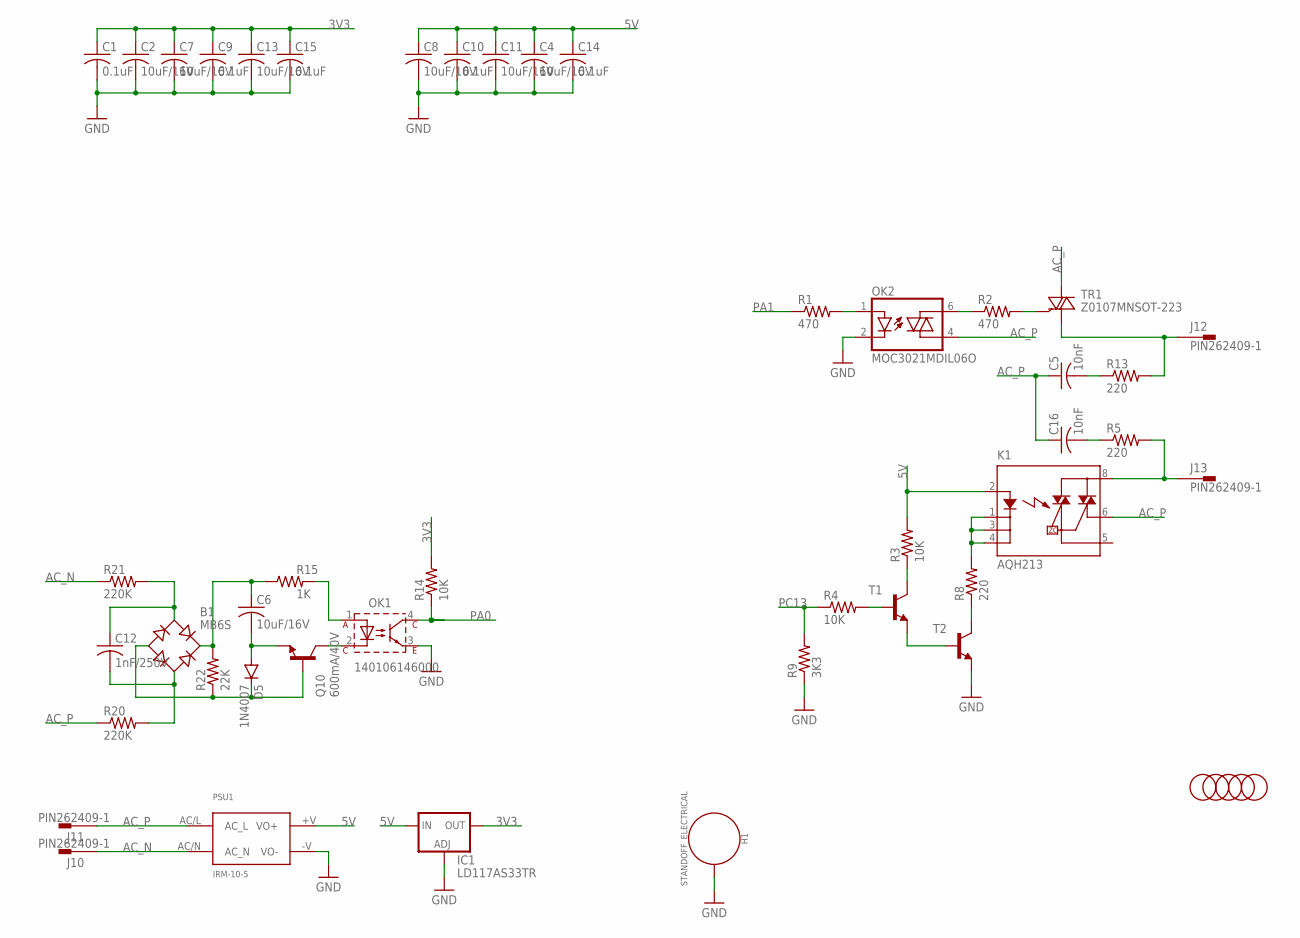
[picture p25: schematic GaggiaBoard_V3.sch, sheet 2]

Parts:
B1: MB6S; SOIC-4; LCSC C2487
C1, C9, C10, C14, C15: 0.1uF; C0603; LCSC C1591
C2, C4, C6, C7, C8, C11, C13: 10uF/16V; C0603; LCSC C86275
C5, C16: 10nF; C1206; LCSC C107192
C12: 1nF/250V; C0603; LCSC C277510
D5: 1N4007; DO214AC; LCSC C727081
H1: STANDOFF_ELECTRICAL; STANDOFF-ELECTRICAL
IC1: LD117AS33TR; SOT223; LCSC C26537
J10, J11, J12, J13: PIN262409-1; 62409-1; LCSC C86495
K1: AQH213; DIL07; LCSC C719560
MARK3, MARK4, MARK6, MARK7, MARK8: FIDUCIAL; FIDUCIAL_1MM
OK1: 140106146000; WL-OCPT_LSOP4; LCSC C141610
OK2: MOC3021MDIL06O; DIL06O; LCSC C5242
PSU1: IRM-10-5; IRM-10; LCSC C2857903
Q10: 600mA/40V; SOT23-3; LCSC C82460
R1, R2: 470; R0603; LCSC C114669
R3, R4, R14: 10K; R0603; LCSC C98220
R5, R13: 220; R2512; LCSC C877859
R8: 220; R0603; LCSC C107696
R9: 3K3; R0603; LCSC C114432
R15: 1K; R0603; LCSC C22548
R20, R21: 220K; R1206; LCSC C130275
R22: 22K; R0603; LCSC C114065
T1, T2: MMBT2222ALT1-NPN-SOT23-BEC; SOT23-BEC; LCSC C82460
TR1: Z0107MNSOT-223; SOT223; LCSC C71218

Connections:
3V3: C1.1, C2.1, C7.1, C9.1, C13.1, C15.1, IC1.4 (OUT), R14.2; also elsewhere on the board
3WAY: J13.A1, J13.A2, K1.8 (DS1), R5.2
5V: C4.1, C8.1, C10.1, C11.1, C14.1, IC1.3 (IN), K1.2 (A), PSU1.+V (VO+), R3.2; also elsewhere on the board
AC_N: J10.A1, J10.A2, PSU1.AC/N (AC_N), R21.1
AC_P: C5.1, C16.1, J11.A1, J11.A2, K1.6 (DS3), OK2.4 (A1), PSU1.AC/L (AC_L), R20.1, TR1.2 (A2), TR1.4 (A2)
GND: C1.2, C2.2, C4.2, C7.2, C8.2, C9.2, C10.2, C11.2, C13.2, C14.2, C15.2, H1.P1, IC1.1 (ADJ), OK1.3, OK2.2 (C), PSU1.-V (VO-), R9.1, T2.E; also elsewhere on the board
unnamed: R3.1, T1.C
unnamed: B1.-, D5.C, Q10.1 (B), R22.1
unnamed: OK1.2, Q10.3 (C)
unnamed: OK2.6 (A2), R2.1
unnamed: R2.2, TR1.3 (G)
unnamed: R8.1, T2.C
unnamed: T1.E, T2.B
unnamed: K1.1 (K), K1.3 (K1), K1.4 (K2), R8.2
unnamed: R4.2, T1.B
unnamed: C16.2, R5.1
unnamed: C5.2, R13.1
unnamed: B1.~1 (AC1), C12.2, R20.2
unnamed: B1.~2 (AC2), C12.1, R21.2
unnamed: OK2.1 (A), R1.2
unnamed: C6.2, D5.A, Q10.2 (E)
unnamed: OK1.1, R15.2
unnamed: B1.+, C6.1, R15.1, R22.2
PA0: OK1.4, R14.1; also elsewhere on the board
PA1: R1.1; also elsewhere on the board
PC13: R4.1, R9.2; also elsewhere on the board
PUMP_P: J12.A1, J12.A2, R13.2, TR1.1 (A1)

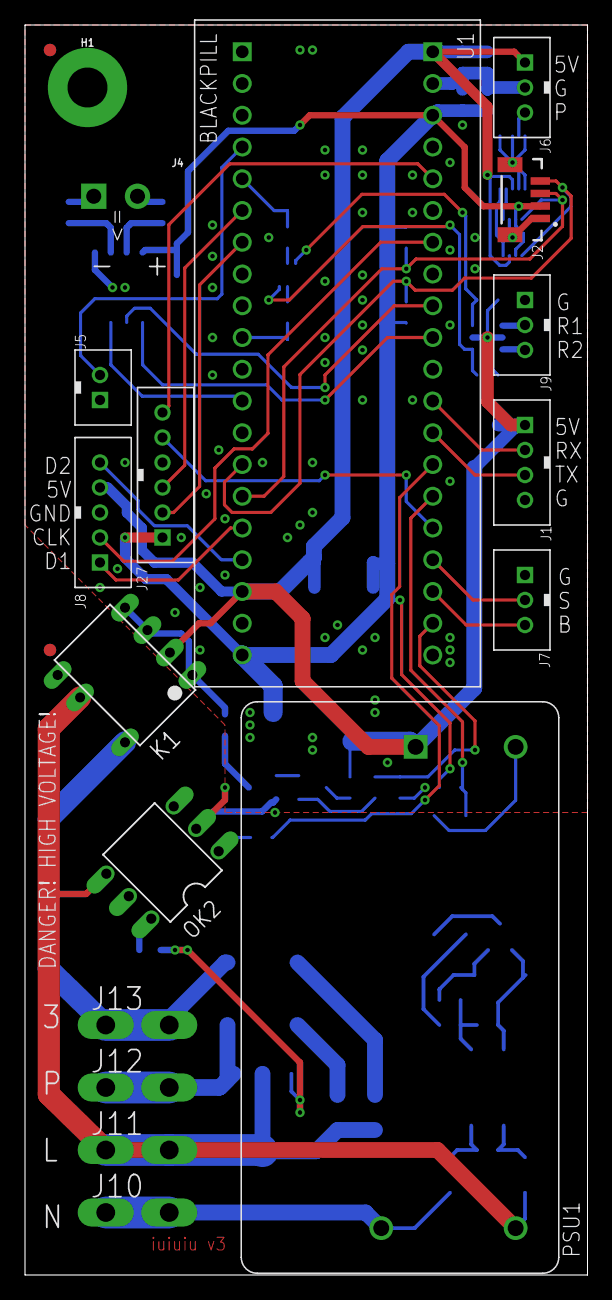
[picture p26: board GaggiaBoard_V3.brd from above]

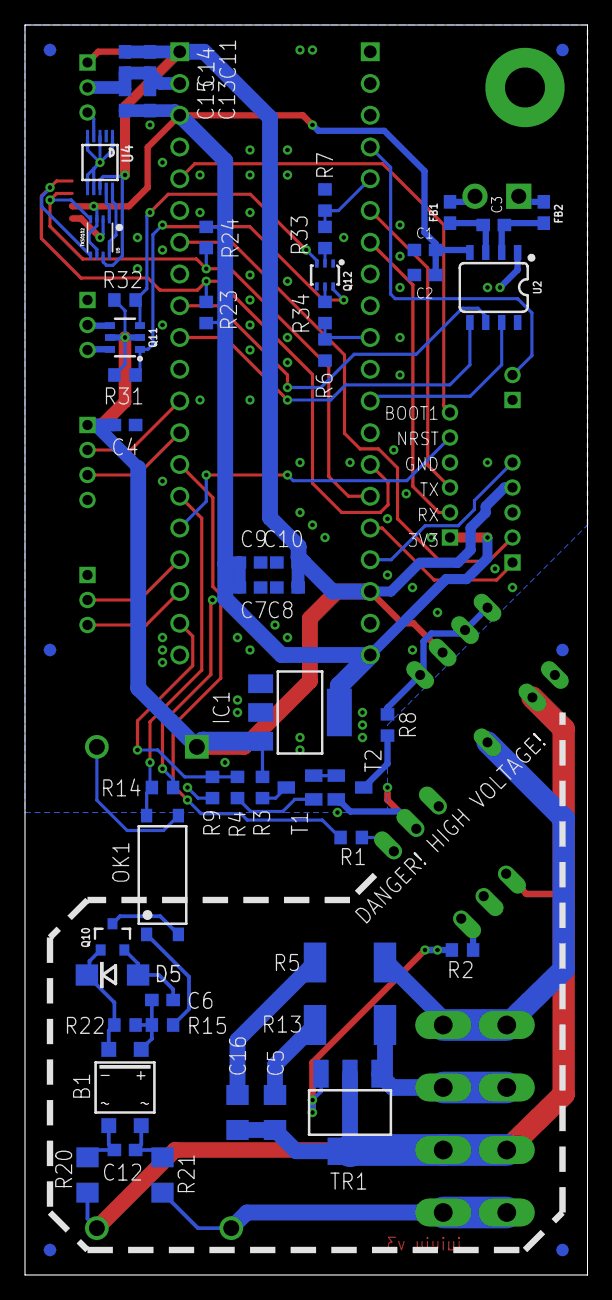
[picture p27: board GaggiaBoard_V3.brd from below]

Board: 2 copper layers, 45.0 x 100.0 mm, 78 parts (58 on the bottom side), 59 nets.

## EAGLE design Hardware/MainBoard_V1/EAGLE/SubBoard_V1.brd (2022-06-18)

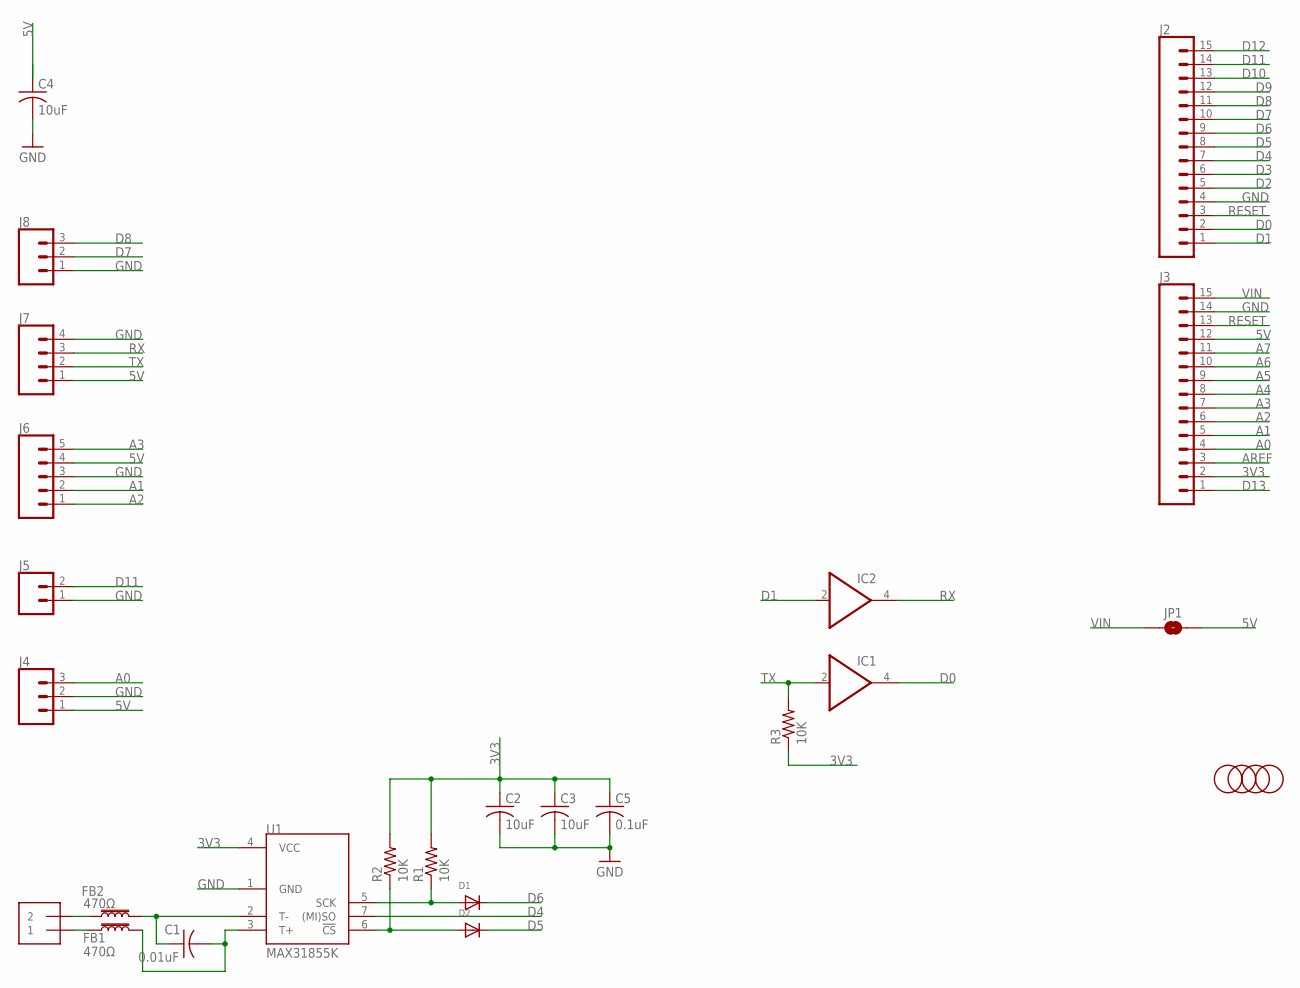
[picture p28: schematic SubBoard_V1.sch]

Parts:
C1: 0.01uF; C0603; LCSC C1589
C2, C3, C4: 10uF; C0603; LCSC C19702
C5: 0.1uF; C0603; LCSC C1591
D1, D2: DIODESOD-523; SOD-523; LCSC C232841
FB1, FB2: 470Ω; 0603; LCSC C883591
IC1, IC2: 74LVC1G07DBV; SOT23-5; LCSC C7829
J1: 1X2-3.5MM; LCSC C474892
J2, J3: CONN_15; 1X15; LCSC C2897378
J4, J8: CONN_03JST-PTH; JST-3-PTH; LCSC C157929
J5: CONN_02JST-PTH-2; JST-2-PTH; LCSC C173752
J6: CONN_05JST; JST-5-PTH; LCSC C157923
J7: CONN_04POLAR; MOLEX-1X4; LCSC C163037
JP1: JUMPER-SMT_2_NO_SILK; SMT-JUMPER_2_NO_SILK
R1, R2, R3: 10K; R0402; LCSC C60490
U1: MAX31855K; SO08; LCSC C52028
U$1, U$2, U$3, U$4: FIDUCIAL; FIDUCIAL_1MM

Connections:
3V3: C2.1, C3.1, C5.1, IC1.5 (VCC), IC2.5 (VCC), J3.2, R1.2, R2.2, R3.1, U1.4 (VCC)
5V: C4.1, J3.12, J4.1, J6.4, J7.1, JP1.2
A0: J3.4, J4.3
A1: J3.5, J6.2
A2: J3.6, J6.1
A3: J3.7, J6.5
A4: J3.8
A5: J3.9
A6: J3.10
A7: J3.11
AREF: J3.3
D0: IC1.4 (O), J2.2
D1: IC2.2 (I), J2.1
D2: J2.5
D3: J2.6
D4: J2.7, U1.7 ((MI)SO)
D5: D2.K (C), J2.8
D6: D1.K (C), J2.9
D7: J2.10, J8.2
D8: J2.11, J8.3
D9: J2.12
D10: J2.13
D11: J2.14, J5.2
D12: J2.15
D13: J3.1
GND: C2.2, C3.2, C4.2, C5.2, IC1.3 (GND), IC2.3 (GND), J2.4, J3.14, J4.2, J5.1, J6.3, J7.4, J8.1, U1.1 (GND)
unnamed: FB2.1, J1.2
unnamed: FB1.1, J1.1
unnamed: C1.1, FB2.2, U1.2 (T-)
unnamed: D1.A, R1.1, U1.5 (SCK)
unnamed: C1.2, FB1.2, U1.3 (T+)
unnamed: D2.A, R2.1, U1.6 (!CS)
RESET: J2.3, J3.13
RX: IC2.4 (O), J7.3
TX: IC1.2 (I), J7.2, R3.2
VIN: J3.15, JP1.1

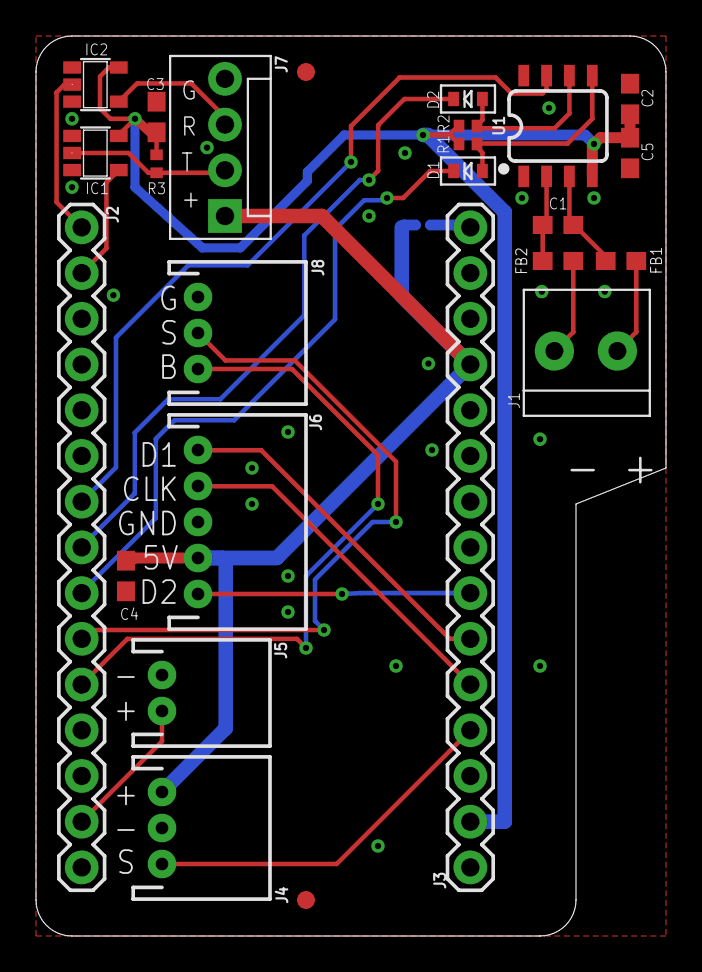
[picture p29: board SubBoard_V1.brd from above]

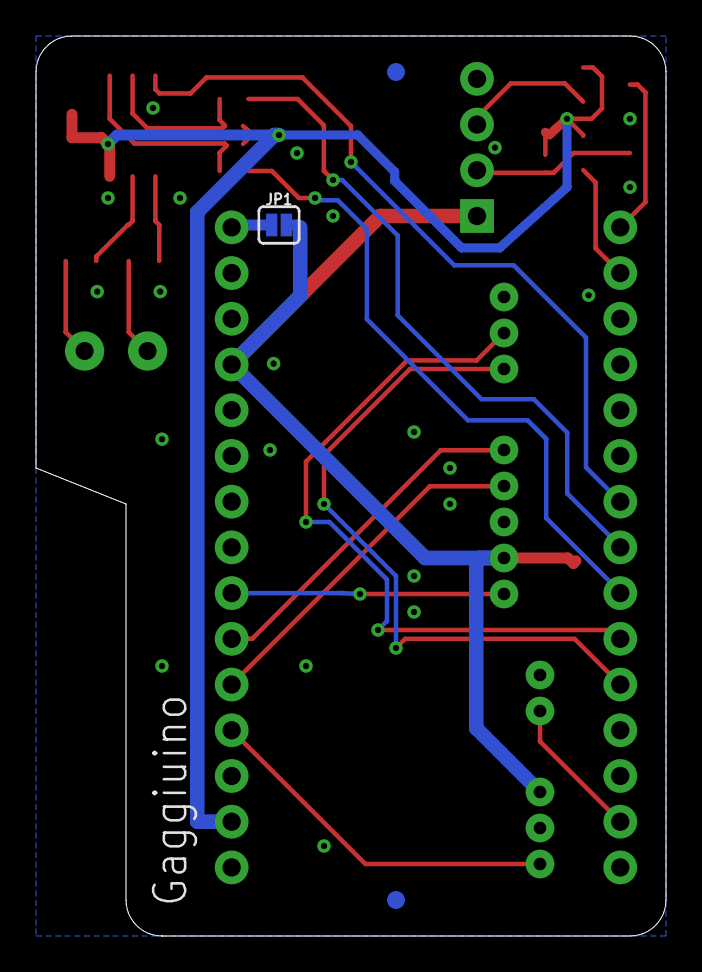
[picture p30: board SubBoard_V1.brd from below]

Board: 2 copper layers, 35.0 x 50.0 mm, 28 parts (3 on the bottom side), 25 nets.

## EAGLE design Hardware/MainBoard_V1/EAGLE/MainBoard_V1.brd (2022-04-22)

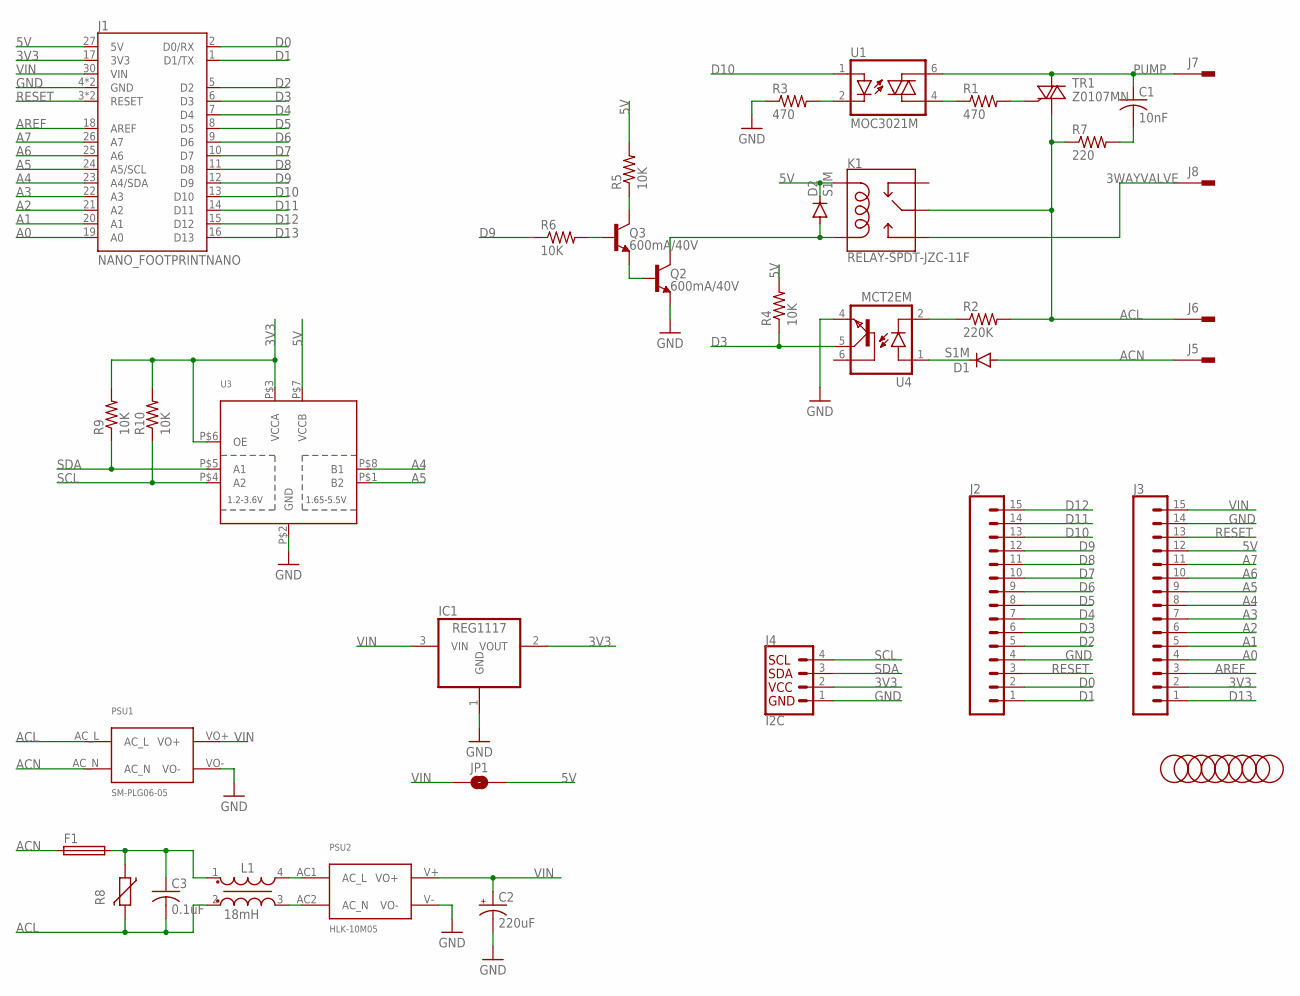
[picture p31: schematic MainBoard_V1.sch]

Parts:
C1: 10nF; C075-032X103; LCSC C2893639
C2: 220uF; E2,5-6
C3: 0.1uF; C150-054X183
D1, D2: S1M; SMA; LCSC C155378
F1: FUSETE5; TE5
IC1: REG1117; SOT223; LCSC C26537
J1: NANO_FOOTPRINTNANO; NANO
J2, J3: CONN_15; 1X15; LCSC C2894938
J4: I2C; JST04_1MM_VERT; LCSC C160390
J5, J6, J7, J8: PIN262409-1; 62409-1; LCSC C305817
JP1: JUMPER-SMT_2_NO_SILK; SMT-JUMPER_2_NO_SILK
K1: RELAY-SPDT-JZC-11F; RELAY-JZC; LCSC C74541
L1: 18mH; WE-TFC_UU9.8V
PSU1: SM-PLG06-05; SM-PLG06
PSU2: HLK-10M05; HLK-10MXX
Q2, Q3: 600mA/40V; SOT23-3; LCSC C82460
R1, R3: 470; R0603; LCSC C23179
R2: 220K; R0603; LCSC C22961
R4, R5, R6, R9, R10: 10K; R0603; LCSC C98220
R7: 220; R2512; LCSC C38808
R8: VARISTOR-7,5; R-7,5
TR1: Z0107MN; SOT223; LCSC C145130
U1: MOC3021M; DIL06; LCSC C123202
U3: TXS0102; VFSOP-8; LCSC C2677417
U4: MCT2EM; PDIP6_8P89X6P60_ONS; LCSC C258259
U$1, U$2, U$3, U$4, U$5, U$6, U$7, U$8: FIDUCIAL; FIDUCIAL_1MM

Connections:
3V3: IC1.2 (VOUT), J1.17 (3V3), J3.2, J4.2, R9.2, R10.2, U3.P$3 (VCCA), U3.P$6 (OE)
3WAYVALVE: J8.A1, J8.A2, K1.3 (NO)
5V: D2.C, J1.27 (5V), J3.12, JP1.2, K1.5 (COIL1), R4.2, R5.2, U3.P$7 (VCCB)
A0: J1.19 (A0), J3.4
A1: J1.20 (A1), J3.5
A2: J1.21 (A2), J3.6
A3: J1.22 (A3), J3.7
A4: J1.23 (A4/SDA), J3.8, U3.P$8 (B1)
A5: J1.24 (A5/SCL), J3.9, U3.P$1 (B2)
A6: J1.25 (A6), J3.10
A7: J1.26 (A7), J3.11
ACL: C3.2, J6.A1, J6.A2, K1.4 (MAIN), L1.2, PSU1.AC_L, R2.2, R7.1, R8.2, TR1.1 (A1)
ACN: D1.A, F1.1, J5.A1, J5.A2, PSU1.AC_N
ACN1: C3.1, F1.2, L1.1, R8.1
AREF: J1.18 (AREF), J3.3
D0: J1.2 (D0/RX), J2.2
D1: J1.1 (D1/TX), J2.1
D2: J1.5 (D2), J2.5
D3: J1.6 (D3), J2.6, R4.1, U4.5 (COL)
D4: J1.7 (D4), J2.7
D5: J1.8 (D5), J2.8
D6: J1.9 (D6), J2.9
D7: J1.10 (D7), J2.10
D8: J1.11 (D8), J2.11
D9: J1.12 (D9), J2.12, R6.1
D10: J1.13 (D10), J2.13, U1.1 (A)
D11: J1.14 (D11), J2.14
D12: J1.15 (D12), J2.15
D13: J1.16 (D13), J3.1
GND: C2.-, IC1.1 (GND), J1.4 (GND), J1.29 (GND), J2.4, J3.14, J4.1, PSU1.VO-, PSU2.V- (VO-), Q2.2 (E), R3.1, U3.P$2 (GND), U4.4 (EMI)
unnamed: R1.1, U1.4 (A1)
unnamed: R1.2, TR1.3 (G)
unnamed: R3.2, U1.2 (C)
unnamed: C1.2, R7.2
unnamed: R2.1, U4.2 (C)
unnamed: D1.C, U4.1 (A)
unnamed: L1.4, PSU2.AC1 (AC_L)
unnamed: Q2.1 (B), Q3.2 (E)
unnamed: D2.A, K1.1 (COIL2), Q2.3 (C)
unnamed: Q3.3 (C), R5.1
unnamed: Q3.1 (B), R6.2
unnamed: L1.3, PSU2.AC2 (AC_N)
PUMP: C1.1, J7.A1, J7.A2, TR1.2 (A2), TR1.4 (A2), U1.6 (A2)
RESET: J1.3 (RESET), J1.28 (RESET), J2.3, J3.13
SCL: J4.4, R10.1, U3.P$4 (A2)
SDA: J4.3, R9.1, U3.P$5 (A1)
VIN: C2.+, IC1.3 (VIN), J1.30 (VIN), J3.15, JP1.1, PSU1.VO+, PSU2.V+ (VO+)



Board: 2 copper layers, 94.0 x 54.0 mm, 45 parts (6 on the bottom side), 47 nets.

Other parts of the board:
U$9: HV_LOGO_3

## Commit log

2021-12-03 Initial state
    [MainBoard_V1.brd, MainBoard_V1.sch]
2021-12-03 Gerber files (alpha version)
2021-12-19 Bug fix
    [MainBoard_V1.brd, MainBoard_V1.sch]
2021-12-22 New folder structure
    [MainBoard_V1.brd, MainBoard_V1.sch]
2021-12-23 Fiducials added
    [GaggiaBoard_V1.brd, GaggiaBoard_V1.sch]
2021-12-23 UART level shifter
    [GaggiaBoard_V1.brd, GaggiaBoard_V1.sch]
2022-02-04 SubBoard_V1 initial state
    [MainBoard_V1.brd, MainBoard_V1.sch, SubBoard_V1 - Base.brd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]
2022-02-07 Mounting holes
    [MainBoard_V1.brd, MainBoard_V1.sch]
2022-02-08 Layout optimization
    [SubBoard_V1.brd]
2022-02-09 All SMD to the top layer
    [MainBoard_V1.brd, MainBoard_V1.sch]
2022-02-10 SubBoard exports
    [SubBoard_V1.brd, SubBoard_V1.sch]
2022-02-10 MainBoard BOM update
2022-02-10 GaggiaBoard BOM update
    [GaggiaBoard_V1.brd, GaggiaBoard_V1.sch]
2022-02-16 Warning symbols added
    [GaggiaBoard_V1.brd, MainBoard_V1.brd]
2022-03-04 Switch pullups added
    [SubBoard_V1.brd, SubBoard_V1.sch]
2022-03-13 I2C pullups
    [MainBoard_V1.brd, MainBoard_V1.sch]
2022-04-22 Layout change
    [SubBoard_V1.brd, SubBoard_V1.sch]
2022-04-22 Boiler SSR pin relocation
    [SubBoard_V1.brd, SubBoard_V1.sch]
2022-04-22 Spade connectors BOM fix
    [MainBoard_V1.brd, MainBoard_V1.sch]
2022-05-02 Nextion full buffer IO
    [SubBoard_V1.brd, SubBoard_V1.sch]
2022-05-09 PSU replaced
    [GaggiaBoard_V1.brd, GaggiaBoard_V1.sch]
2022-05-09 Pin assignment updated
2022-05-10 MEAN WELL PSU option, discrete level shifters
    [GaggiaBoard_V1.brd, GaggiaBoard_V1.sch]
2022-05-10 TXU0102 level shifter for SSRs
    [GaggiaBoard_V1.brd, GaggiaBoard_V1.sch]
2022-05-14 UARTs reassigned, LEDs fixed
    [GaggiaBoard_V1.brd, GaggiaBoard_V1.sch]
2022-05-21 Connectors spacing fixed
    [GaggiaBoard_V1.brd, GaggiaBoard_V1.sch]
2022-06-03 Layout update
    [GaggiaBoard_V1.brd, GaggiaBoard_V1.sch]
2022-06-05 Scales port change to PB
    [GaggiaBoard_V1.brd, GaggiaBoard_V1.sch]
2022-06-10 Connector spacing fixed
    [SubBoard_V1.brd]
2022-06-10 Pump bridge rectifier removed, SSR control changed
    [GaggiaBoard_V1.brd, GaggiaBoard_V1.sch]
2022-06-18 Switch reassignment
    [SubBoard_V1.brd, SubBoard_V1.sch]
2022-07-08 V2 initial state
    [GaggiaBoard_V1.brd, GaggiaBoard_V2.brd, GaggiaBoard_V2.sch]
2022-08-14 part list fix
    [GaggiaBoard_V2.brd, GaggiaBoard_V2.sch]
2022-09-16 V2.1 update
    [GaggiaBoard_V2.brd, GaggiaBoard_V2.sch]
2022-09-18 V3 added
    [GaggiaBoard_V3.brd, GaggiaBoard_V3.sch]
2022-09-18 UART added
    [GaggiaBoard_V3.brd, GaggiaBoard_V3.sch]
2022-09-23 README + PC13 load fix
    [GaggiaBoard_V3.brd, GaggiaBoard_V3.sch]
2022-09-25 Centroid added to Gerber
    [GaggiaBoard_V2.brd]
2022-09-28 J1 fix
    [GaggiaBoard_V2.brd, GaggiaBoard_V2.sch, GaggiaBoard_V3.brd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]
2022-11-03 5V supply fix
    [GaggiaBoard_V3.brd]
2022-11-05 stl links
2022-11-17 3-Way valve SSR
    [GaggiaBoard_V2.brd, GaggiaBoard_V2.sch]
2023-02-25 J4 p/n fix
    [GaggiaBoard_V3.brd, GaggiaBoard_V3.sch]
2023-03-05 Faston drill fix
    [GaggiaBoard_V3.brd, GaggiaBoard_V3.sch]
2023-03-16 Steam boiler relays repurpose
2023-03-29 OK1 part change
    [GaggiaBoard_V2.brd, GaggiaBoard_V2.sch]
2023-08-29 pull downs on GPIO outputs
    [GaggiaBoard_V2.brd, GaggiaBoard_V2.sch, GaggiaBoard_V3.brd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]
2023-10-17 Copper pour cutouts for TC
    [GaggiaBoard_V3.brd]
2024-01-21 Snubber change
    [GaggiaBoard_V3.brd, GaggiaBoard_V3.sch]
2025-03-26 v4 schematics

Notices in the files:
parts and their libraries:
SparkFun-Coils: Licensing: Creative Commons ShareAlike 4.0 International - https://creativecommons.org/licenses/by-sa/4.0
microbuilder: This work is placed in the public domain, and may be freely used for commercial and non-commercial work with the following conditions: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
